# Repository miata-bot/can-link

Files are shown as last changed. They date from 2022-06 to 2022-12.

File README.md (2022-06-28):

# Underglow Sync Device

Very much work in progress software and hardware project built with [Kicad](https://www.kicad.org/) for hardware, and C and [Lua](https://www.lua.org) for software. See [The requirements doc](Requirements.md) for the guts of the project.

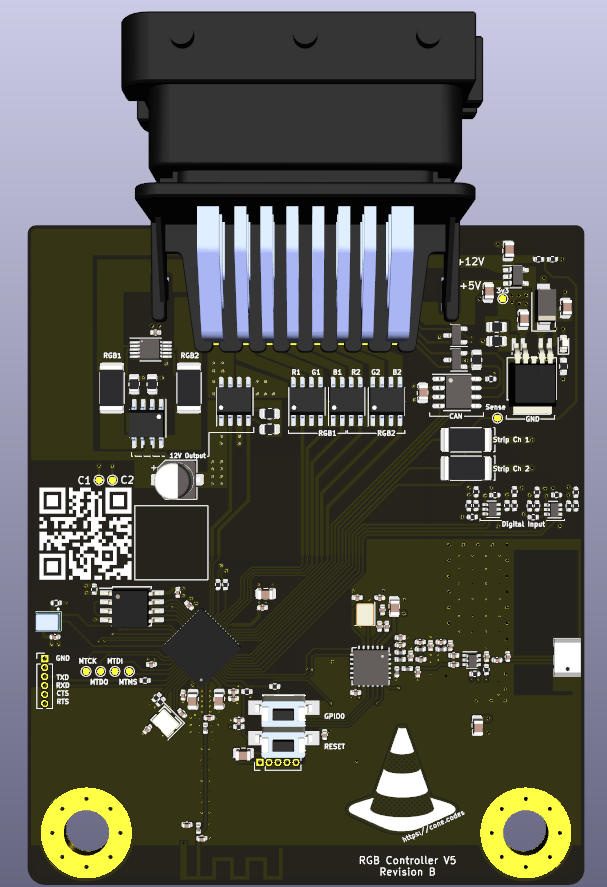
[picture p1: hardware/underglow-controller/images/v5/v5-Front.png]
render


## TLDR

Here's a [Twitter thread](https://twitter.com/pressy4pie/status/1504309482054029315) showing a demo of the ECU integration.
[video link](https://video.twimg.com/ext_tw_video/1504309386151301125/pu/vid/720x1280/zwIcUEVZBSSQAASE.mp4?tag=12).

Here's a [Twitter thread](https://twitter.com/pressy4pie/status/1506779115122139137) showing a demo of the GPS and companion application. [video link](https://video.twimg.com/ext_tw_video/1506778163891740673/pu/vid/720x1630/oxYdaMkSowD5uJmU.mp4?tag=12).

I've written up a few posts on the progress of the project

* [Original hardware design](https://cone.codes/posts/can-link/)
* [Short post on using PWM to drive LEDS](https://cone.codes/posts/nerves-pwm/)
* [Hardware redesign](https://cone.codes/posts/can-link-pt-2/)
* [Hardware reredesign](https://cone.codes/posts/can-link-pt-3/)
* [Hardware rereredesign](https://cone.codes/posts/can-link-pt-4/)
* [Designing a Development test board](https://cone.codes/posts/imx6-devboard/)

## Description

This README acts as a root for all the jillion projects contained within the repo. There is no inherit relationship between any folders. Some are Elixir, some are flutter, etc. One day clean it up. Too much proof of concepting going on right now.

| Folder Name | Description | Language | License |
| ---| --- | --- | --- |
| [hardware](hardware/README.md) | Main hardware designs. Contains schematics, layouts, boms, manufacturing gerbers etc. | KiCad | Creative Commons |
| [firmware](firmware/README.md) | Main Firmware projects. | C++ | MIT |

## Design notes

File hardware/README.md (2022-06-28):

# Hardware Design

Here you'll find the hub for all the sub projects and KiCAD libraries.

| Folder | Description |
| ---| --- |
| [`underglow-controller`](/hardware/underglow-controller/README.md) | RGB controller board |
| - | - |
| [`library`](/hardware/library/README.md) | Library of KiCAD Parts |

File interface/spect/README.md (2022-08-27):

# Software Developer Documentation

These documents are intended for
software developers of potential contributors to
the project's firmware.

## Getting started

First follow the [The getting started guide](Getting-Started.md).
This will take you thru setting up a dev environment to
flash and debug firmware.

## Build Firmware

```bash
cd project_root/firmware/spect
idf.py build
```

## Flash Firmware

1) hold the download button
2) power the device on

```bash
cd project_root/firmware/spect
idf.py flash
```

## Monitor Firmware

```bash
cd project_root/firmware/spect
idf.py monitor
```

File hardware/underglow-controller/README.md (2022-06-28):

# RGB Controller

Device designed to control RGB LEDs and syncronize across multiple nodes
via packet radio.

pcb-front

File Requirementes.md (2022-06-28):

# UNDERGLOW / RGB SYNC PROJECT

I want to make a device that can syncronize underglow
or other RGB lights between two or more cars. Below is a high-level list of all the things I want out of the project.

0) This is not a for profit product, I'm building this for fun.
1) The device should have a CAN interface for aftermarket ECUs and OBD2 capable cars. This notably leaves out interfacing older pre-obd2 cars right now. See [Non CAN enabled applications](#non-can-enabled-systems) for justification and workarounds. See [ECU Support](#ecu-support) for a list of planned support.
2) The device should be WiFi/Bluetooth capable. See the [Hardware](#hardware) section.
3) Every component should be open source where applicable. See the [Licensing](#license) section.
4) It doesn't need to be the cheapest thing. See the [Pricing](#pricing).
5) The device should work offline. See the [Offline Use](#offline-use).
6) The device should create a mesh network to sync devices together. See [Packet Radio](#packet-radio).

## Non CAN Enabled Applications

I decided early on that I simply do not care about this enough to spend time on it. A potential solution to this is an external hardware one. That is, If one wants to inerface a non CAN enabled system, all they would need to do is design their own interface system, and then put their own CAN layer on top. This turns the issue into a software problem, where the interface may be added as a decoder plugin. See the [Firmware Plugin System](#Firmware-Plugin-System) for more info.

## ECU Support

I've written code to support several ECUs already. Much care was put into the system to define how decoding works. It's not "feature complete" yet, but the scafolding is put in place already for dynamic decoder definition. What this means is that I will add support for a handful of common systems up front as I've already done, but adding new ones should be quite easy.

Here's the current supported platform matrix:

| ECU | Coded? | Tested? | Note  |
| --- | --- | --- | ----- |
| MegaSquirt | no | no | Broadcast protocol with default ID |
| Haltech | no | no | Broadcast protocol |
| Maxx | no | no | Default broadcast protocol, too extensible to test every combo? |
| OBD2 | no | no | Enabled in Linux, need to decode messages somehow |
| Speeduino  | no | no | Very similar to MS proto iirc |

## Hardware

~~I've tried this project a few times in the past, and every single time I wish I just started with Linux. I'm sure it's possible to do in an RTOS or even an Arduino system etc. It's just to hard to reason about a system with so much connectivity for me. This puts a much higher price tag because the components selected for the board are just by nature quite a bit more expensive. See the pricing section.~

Designing around a modern SOC right now is just too hard due to the global chip shortage. Maybe I'll try again in the future. For now, I've redesigned the device to use an ESP32-S3 as the "main" chip. ~~and a secondary RP Pico as a coprocessor to do the IO heavy stuff. I'm certain there's better solutions to this but it's what I knew I'd be able to complete without learning a ton of new stuff since I'm on a deadline now.~~

## Firmware

1) The ESP-32 firmware should not use Arduino
2) The firmware should allow for custom plugins via a Lua scripting environment

## Packet Radio

Devices use a RF69 Packet radio to syncronize together. My goal is to keep this system as simple as possible. There should be an accompanying document for the implementation, but the gist of it is that there should be single "producer" node on a network, and many consumers. There may be many networks, they should not interfere. This is accomplished easily via the nature of the packet radios not delivering messages that cannot be decrypted. A network id will just be it's encryption key. This means that networks can be created and destroyed dynamically without collision provided a adequite IDing scheme. UUIDs should work for easy serialization and sharing via QR code or similar. Could also use the ATECCA chip's public key.

One potential idea I have with the radio is to create a "remote" that can control a device similar to the chinese kits. This is of course another piece of hardware that needs to be designed.

## Configuration Interface

There are three ways to configure the device. I plan on shipping a "default" configuration that should just work without any extra setup steps.

The device has a USB mass storage interface that allows storing arbitrary files. I want the main functionality to be implemented in "plugins" (see that section) that can be loaded at runtime. I will ship a default set of plugins to do the some common stuff.

The device has a USB serial port. This means it can be interfaced using existing tools. The first one that comes to mind is Tuner Studio. The INI file could even be stored on the mass storage interface.

The device has a BLE radio. This allows a mobile phone to configure the device via an app.

## Mobile Application

I added BLE onto the device to allow developing a mobile application. I don't really want to make this application myself. I'm hoping this is something I can trick open source passer-bys into building. I've used Flutter to develop a proof of concept application that interfaces the device but it's far from complete. If you're reading this and are interested, get in touch.

## Offline Use

One of my main goals for this device is to have it working in time for [Miatas at the Gap](https://www.gapmiatas.com/) at the end of the year. This means it cannot rely on an active internet connection for use. This does not mean that internet cannot be used, that's why i put a WiFi chip on the board. I don't have any firm planned features that require internet right now, but I do have some ideas. This requirement lead me to use a packet radio for syncing systems together in a meshing network. See [Packet Radio](#packet-radio).

## License

The entire project will be open source. Although I don't expect many direct contributions, I still want the ability for others to be involved with the development easily.

Hardware should be Creative Commons. Software will be mostly MIT or Apache 2. I haven't decied which one yet. Probably Apache 2.

## Pricing

I don't really expect this to be a viable product. The final "price" will probably be whatever it costs to make the device. I may do a croudfunded run of the device depending on what the final BOM turns out to cost. Right now my gut tells me each board will cost about $125 to produce. The passive components are pretty cheap, but there's a lot of them. The CPU is really hard to get right now due to the global chip shortage, same with the WiFi module etc. The connectors are also in short supply.

In the end I don't really care about the price of the device as long as I still find it fun to work on. If I get bored, or interest fades on the idea, I make no commitment to continue producing the device etc.

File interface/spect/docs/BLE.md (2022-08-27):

# BLE Characteristics and Services

## Effect Slot

## Slot

## NodeInfo

Service UUID: ``

| characteristic | name | description |
| - | - | - |
| `` | node list | subscribe then write anything to get a list of nodes |

### Node List

when subscribed to this characteristic, the following payload will be
delievered per each node this device knows about:

| 0..11 | 11..15 | 15-31 |
| node id | reserved | network id |

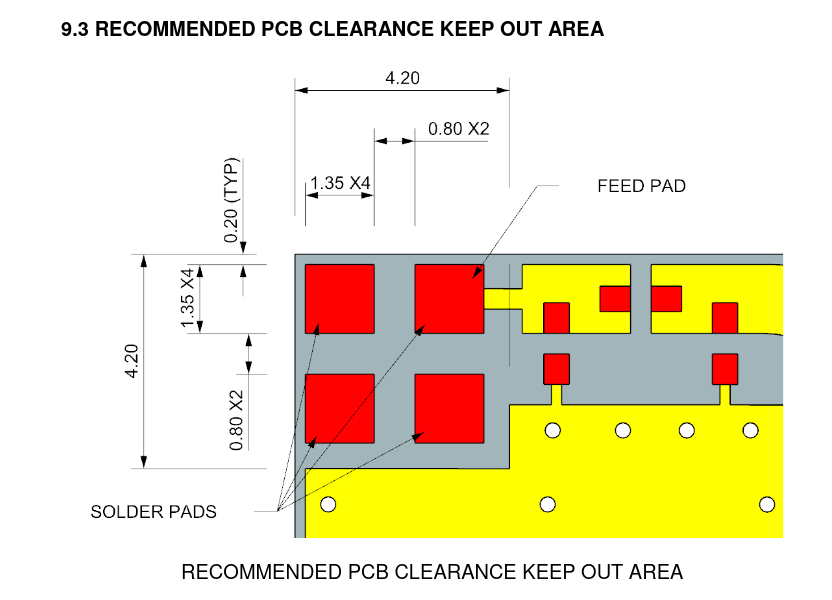
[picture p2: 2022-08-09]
hardware/underglow-controller/images/v5/wifi-antenna-keepout-area.png

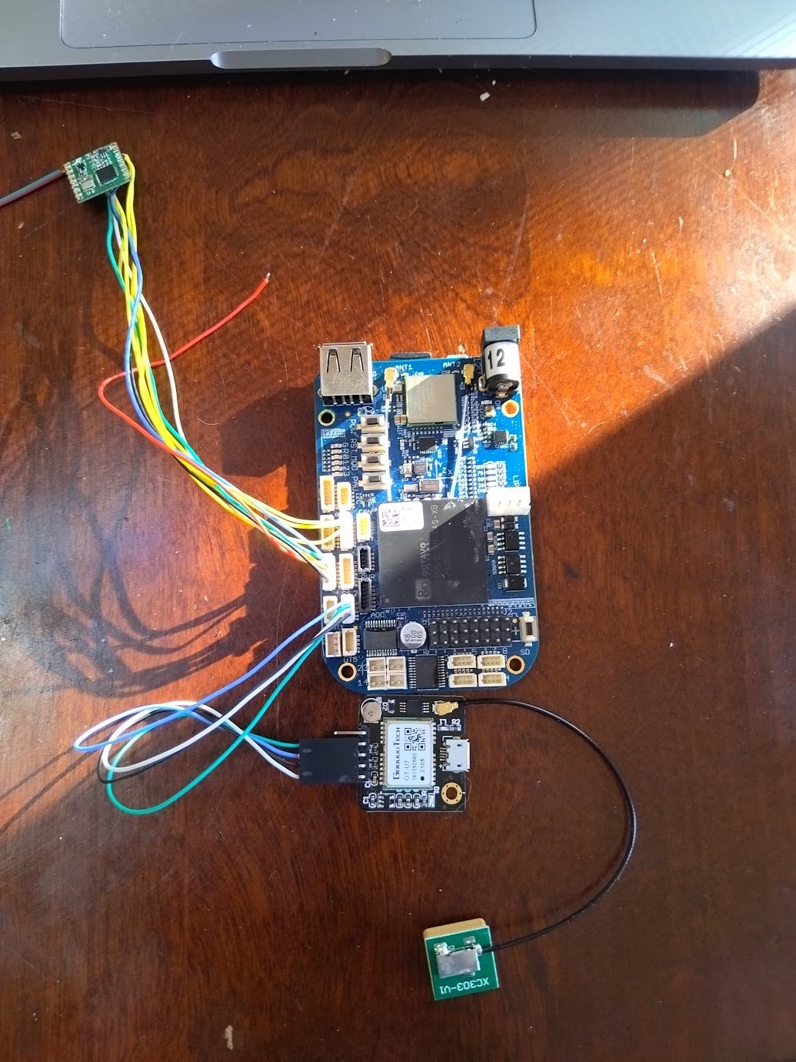
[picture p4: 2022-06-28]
hardware/underglow-controller/images/prototype/beagleblue-prototype.jpg

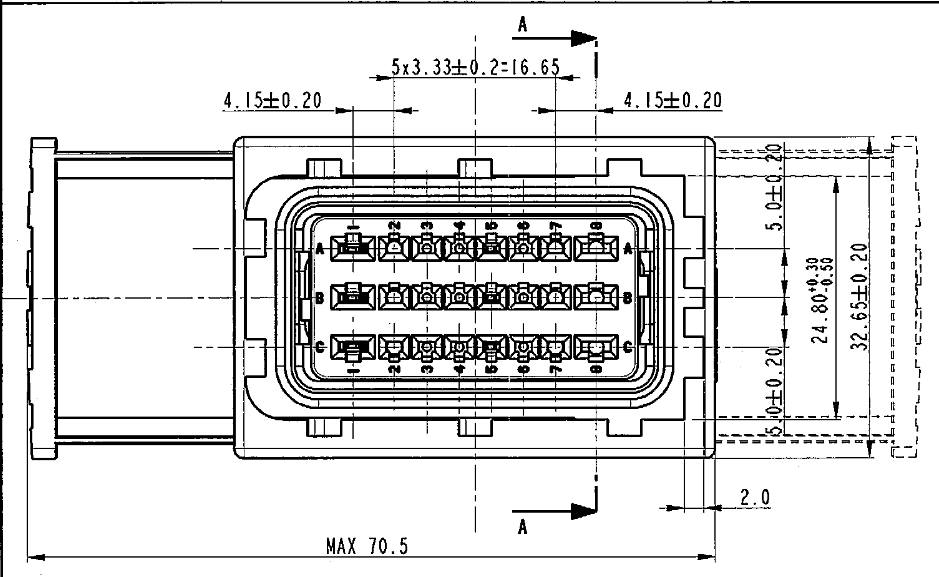
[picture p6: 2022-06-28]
hardware/underglow-controller/images/wiring/Connector-Pinout.png

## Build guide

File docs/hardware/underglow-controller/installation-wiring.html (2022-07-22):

# installation-wiring

## Diagram

## Bill of Materials

Id | Description | Qty | Unit | Designators
1 | Cable, 2 wires | 0 | m | W5
2 | Cable, 3 wires | 0 | m | W6
3 | Cable, 4 wires | 0 | m | Strip1_W1, Strip2_W1, W1, W2
4 | Connector | 2 | | F1, F2
5 | Connector, BK | 3
6 | Connector, Bosch_Style, socket, 5 pins | 1 | | X6
7 | Connector, Delphi_Sicma_24, female, 24 pins | 1 | | X1
8 | Connector, JST SM, female, 4 pins | 12 | | Strip1_X1, Strip1_X2, Strip1_X4, Strip1_X5, Strip1_X7, Strip1_X8, Strip2_X1, Strip2_X2, Strip2_X4, Strip2_X5, Strip2_X7, Strip2_X8
9 | Connector, male, 4 pins | 2 | | X4, X5
10 | Connector, strip, 4 pins | 6 | | Strip1_X3, Strip1_X6, Strip1_X9, Strip2_X3, Strip2_X6, Strip2_X9

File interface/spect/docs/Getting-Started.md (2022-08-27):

# Settingup a development environment

This should be done on Linux. if you're not using Linux,
get rekt i guess.

* clone this repo: `git clone git@github.com:miata-bot/can-link.git`
* clone submodules:  `git submodule --init --recursive`
* install [esp idf](https://docs.espressif.com/projects/esp-idf/en/v4.4.2/esp32s3/get-started/index.html)
* apply patches to sqlite3: `cd firmware/spect/components/esp-idf-sqlite3 && git patch am ../*.patch`
* install [asdf](https://asdf-vm.com/)
* install erlang and elixir: `cd interface/spect && asdf install`
* fetch dependencies: `cd interface/spect && mix deps.get`
* run migrations: `cd interface/spect && mix ecto.migrate`
* build firmware: `cd firmware/spect && idf.py build`

If and only of these stepes succeed should you procede.
Return to the [README](README.md)

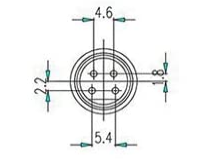
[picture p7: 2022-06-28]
hardware/underglow-controller/images/wiring/RGB-Female.png

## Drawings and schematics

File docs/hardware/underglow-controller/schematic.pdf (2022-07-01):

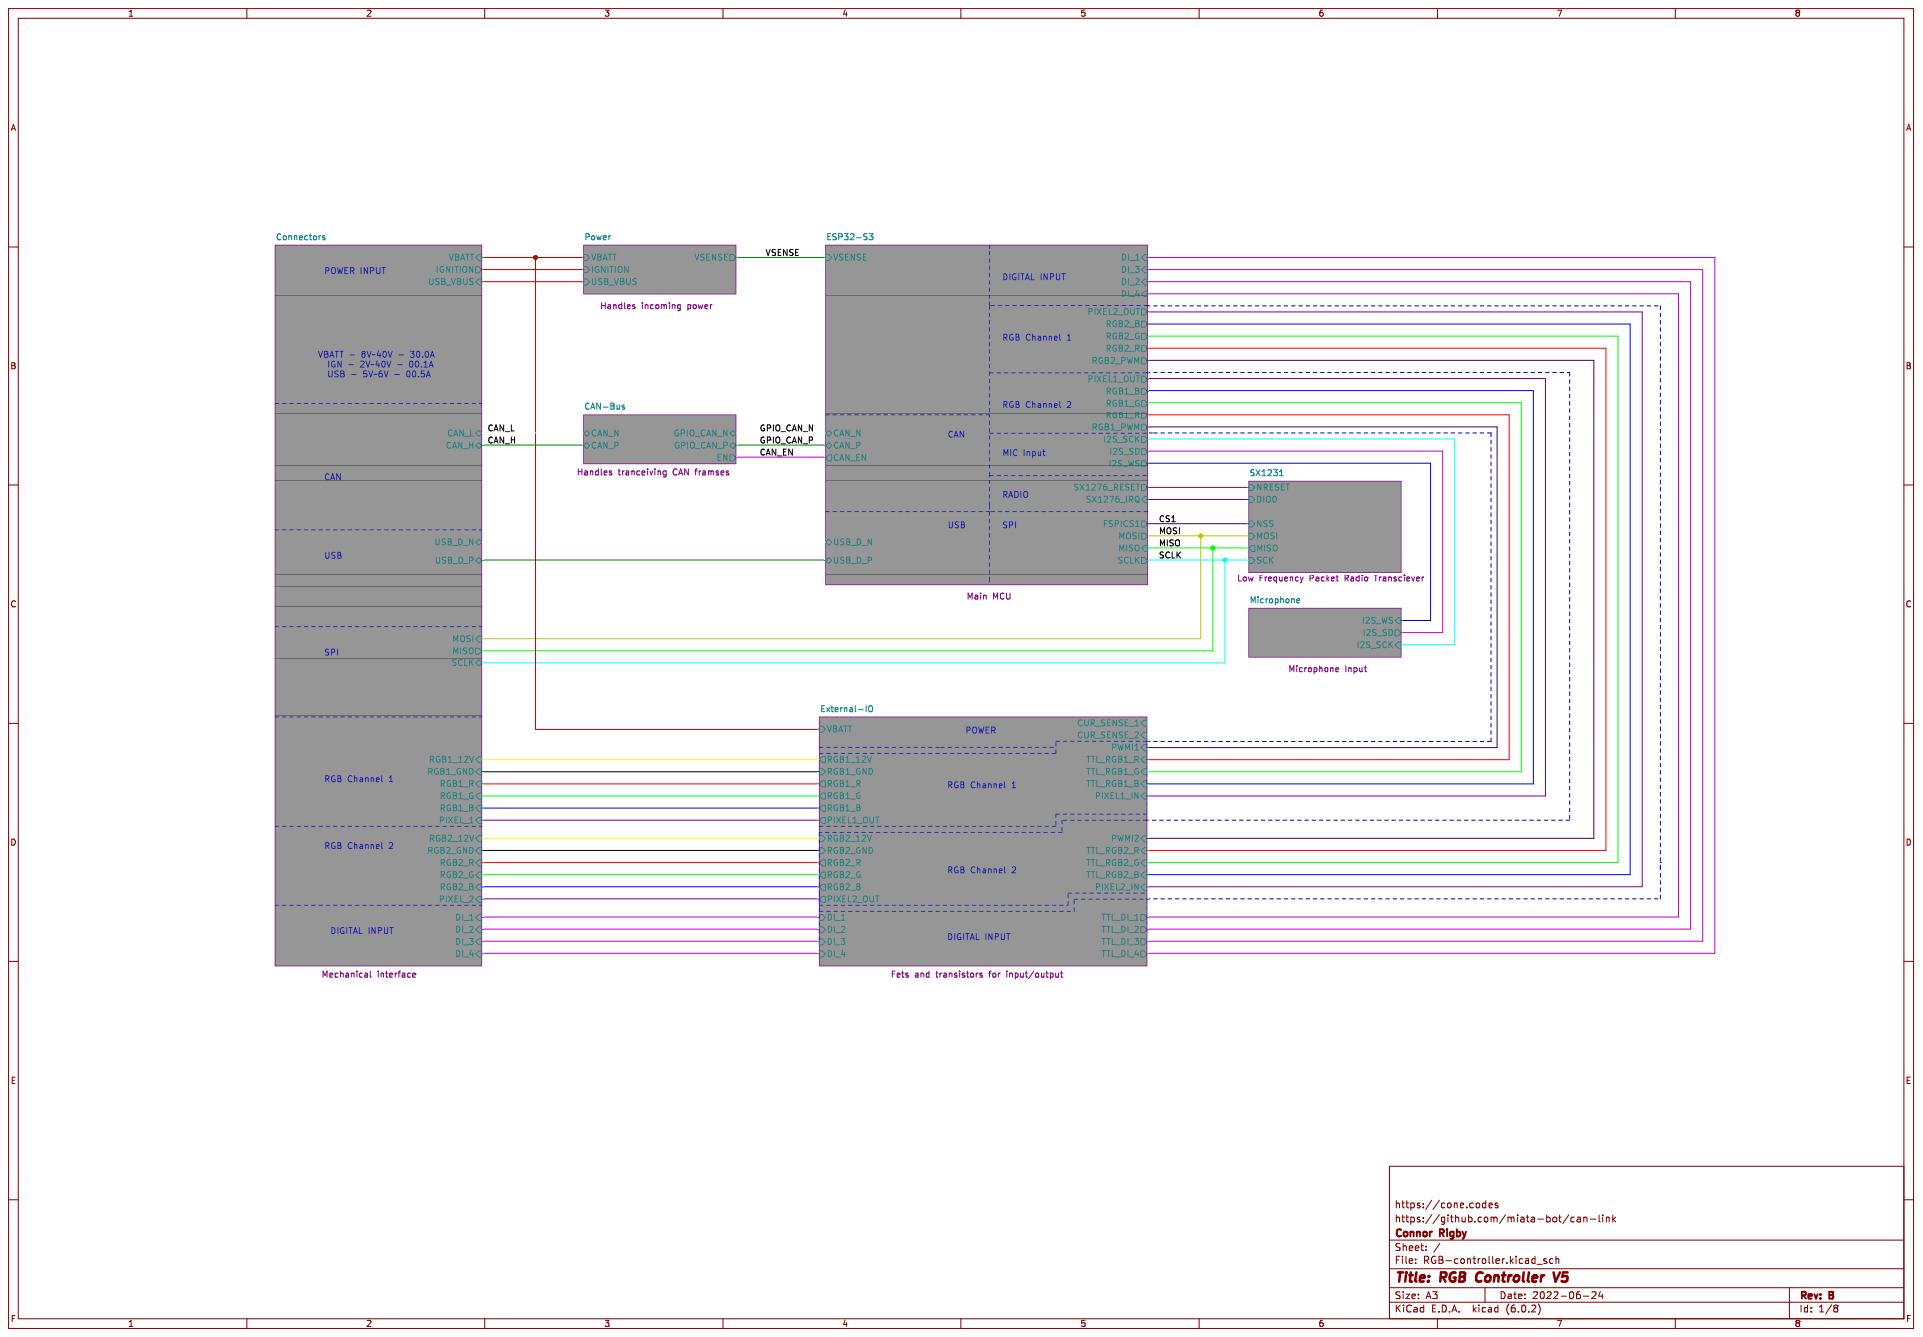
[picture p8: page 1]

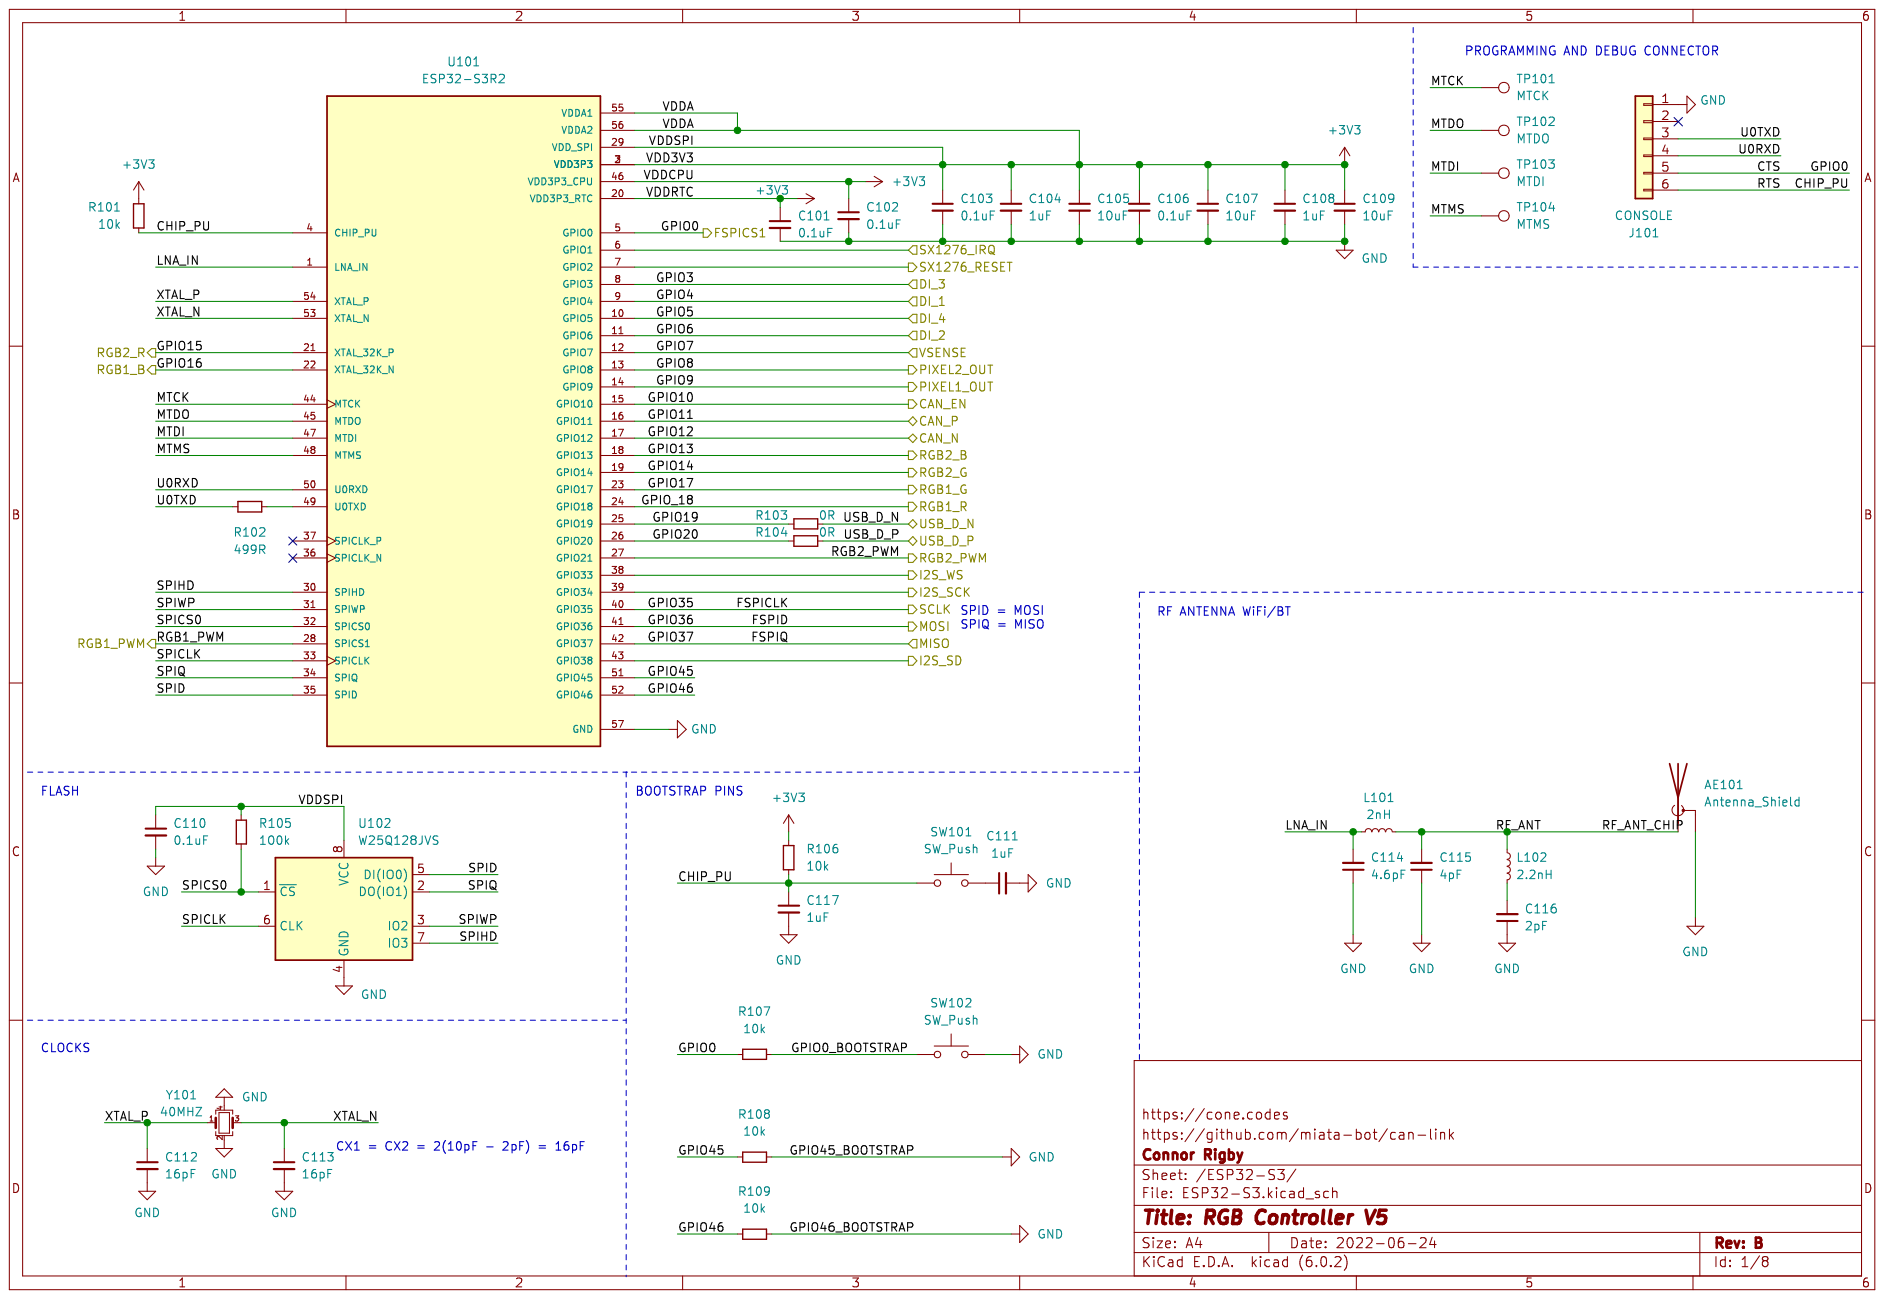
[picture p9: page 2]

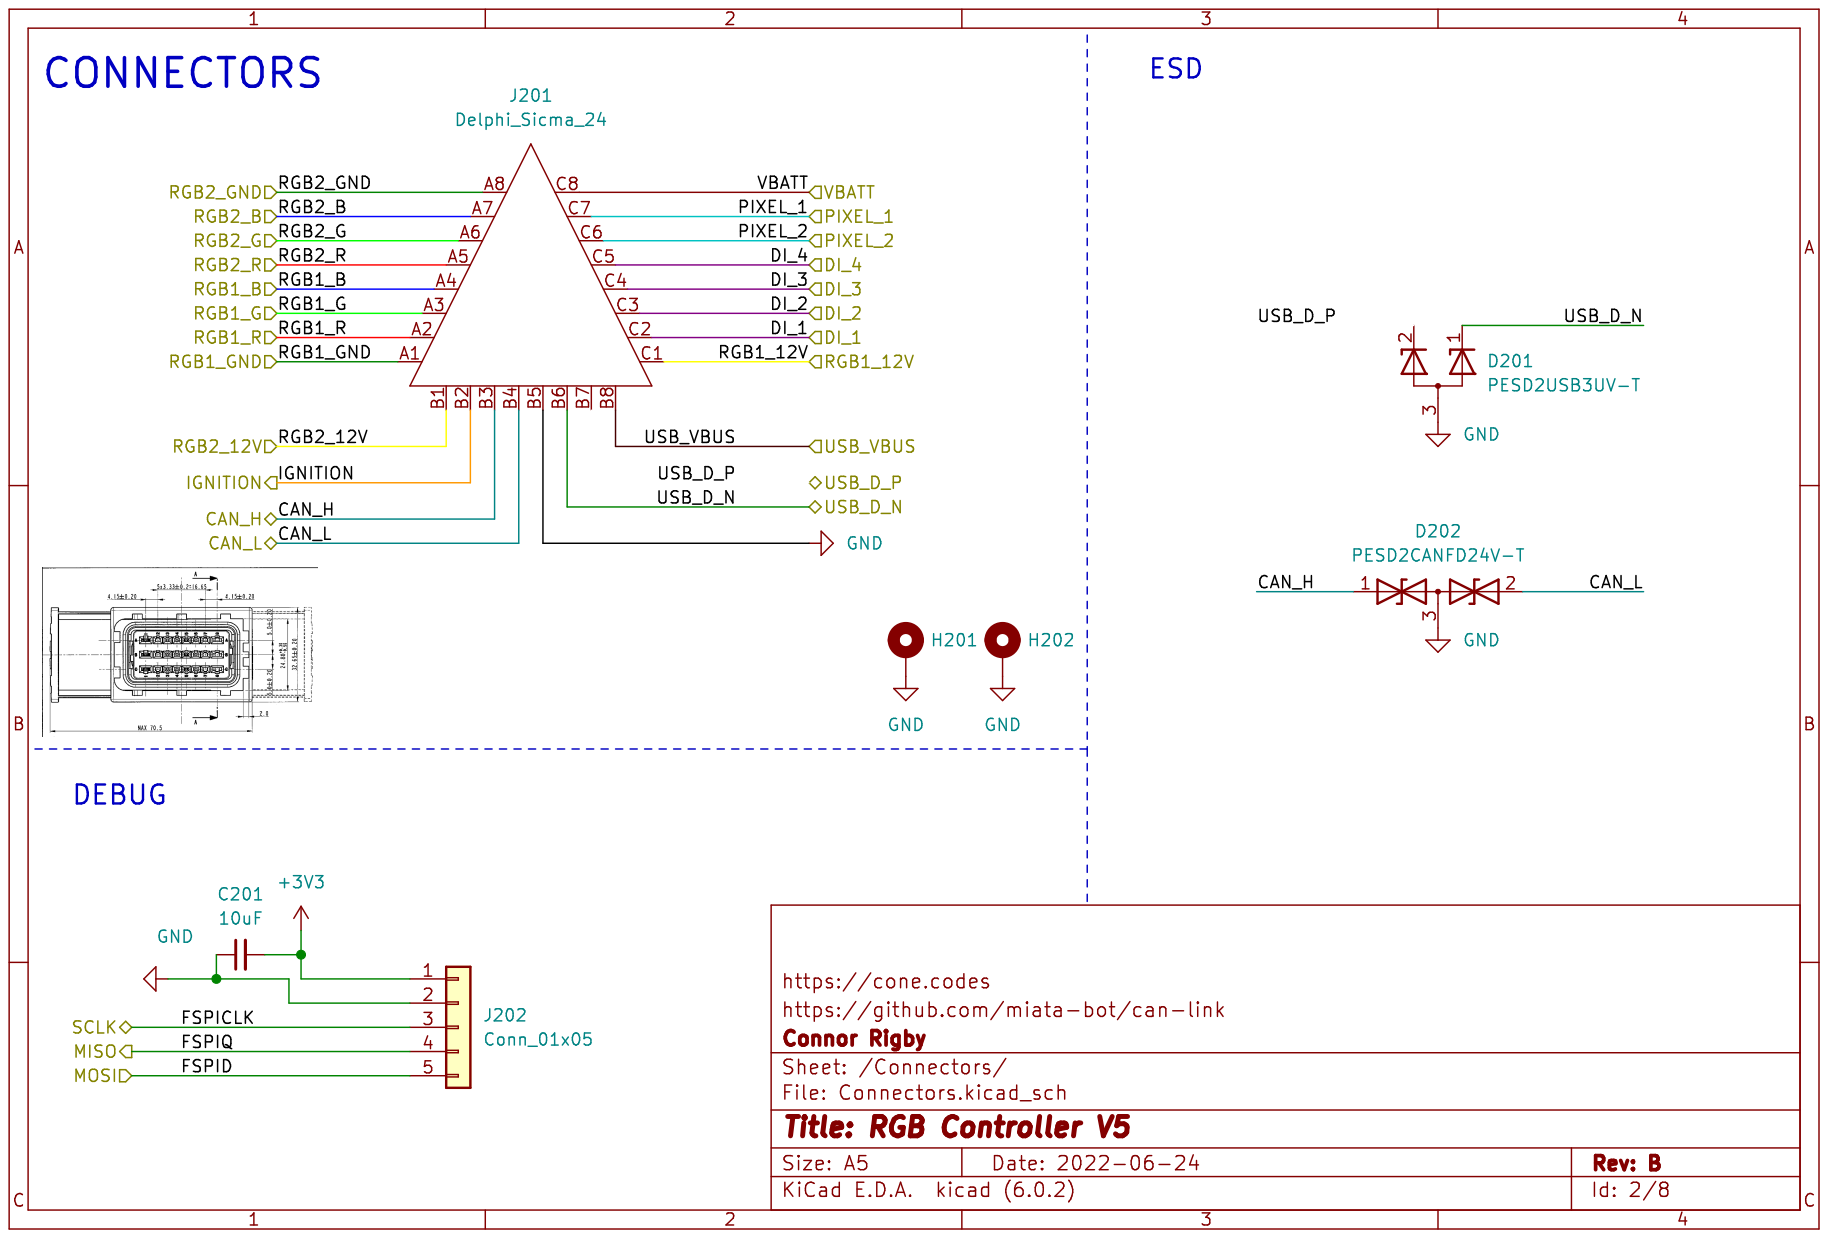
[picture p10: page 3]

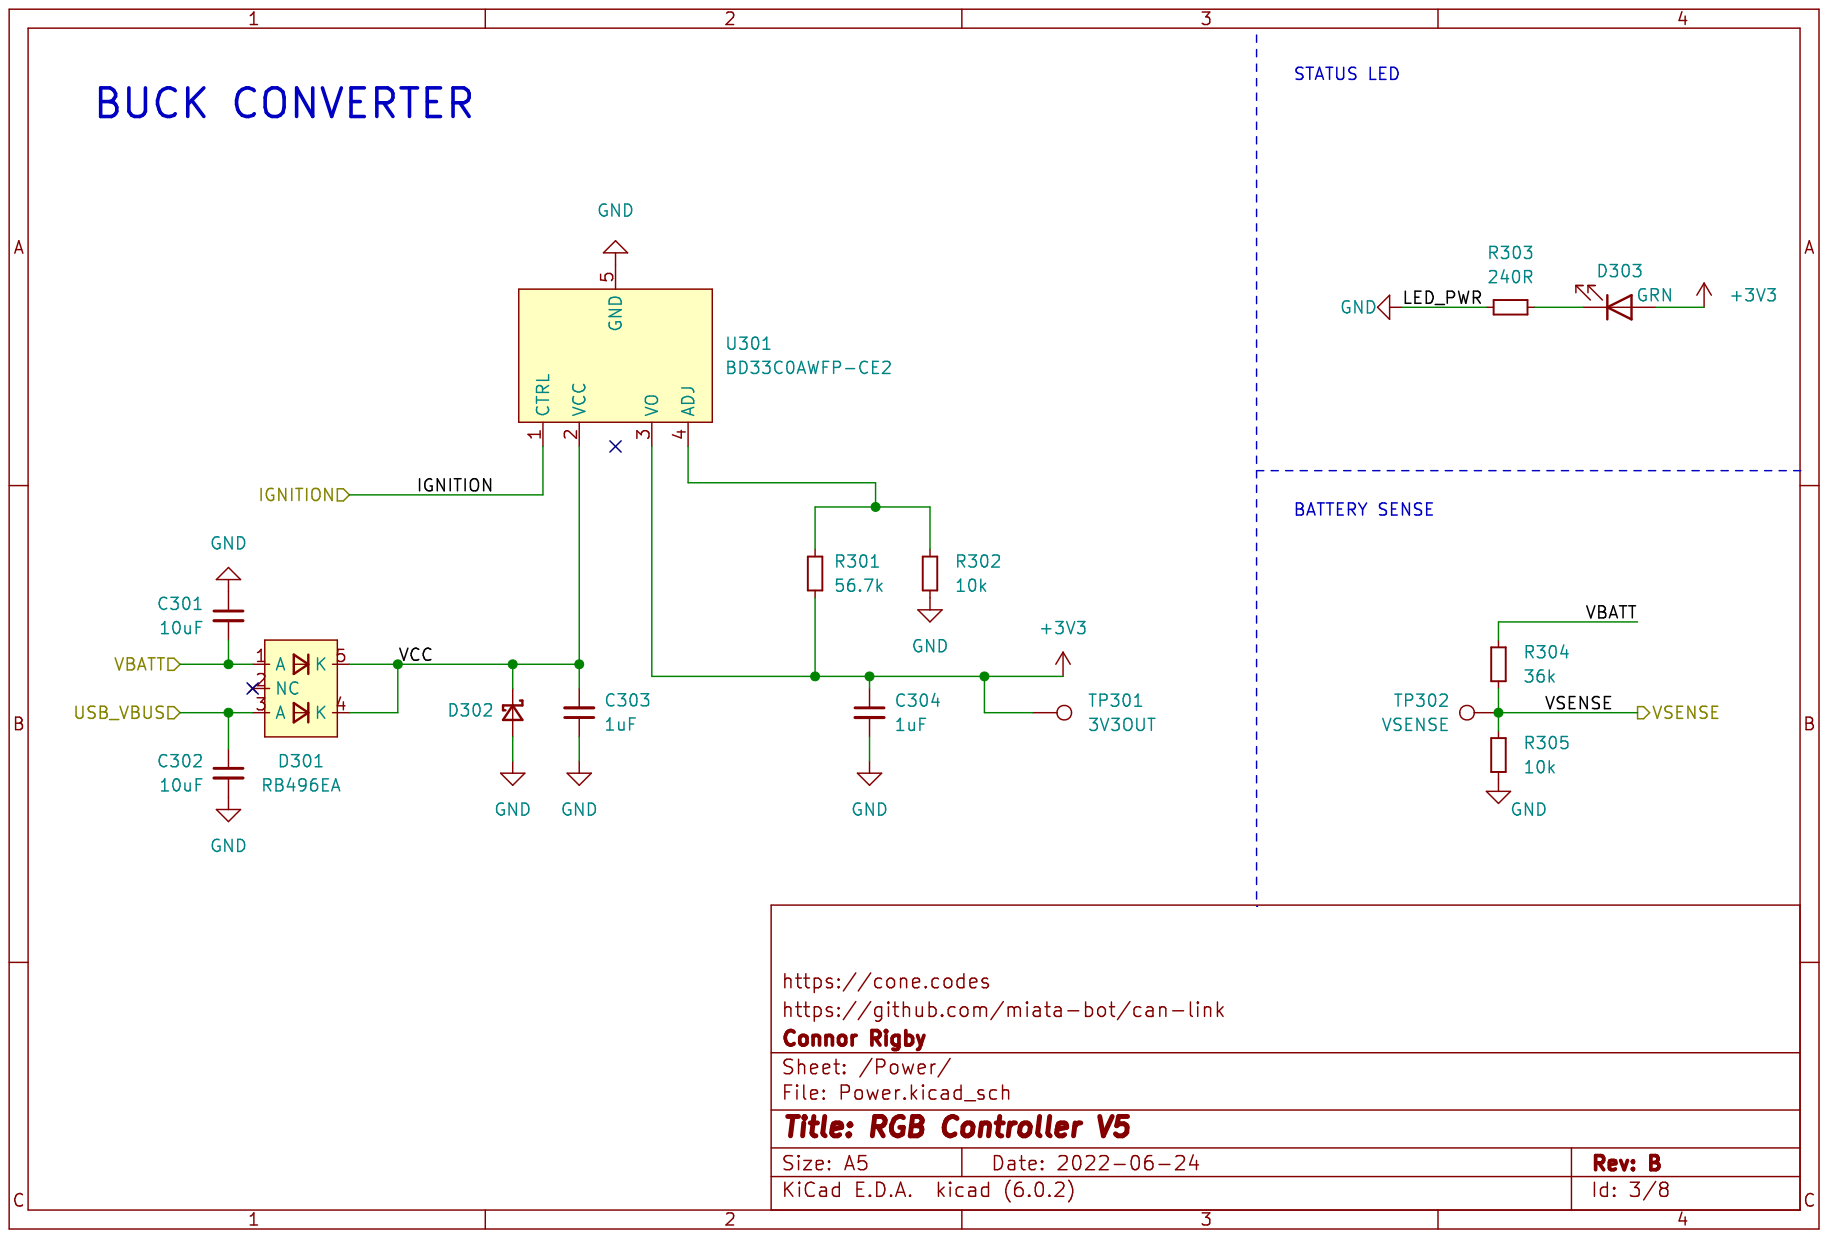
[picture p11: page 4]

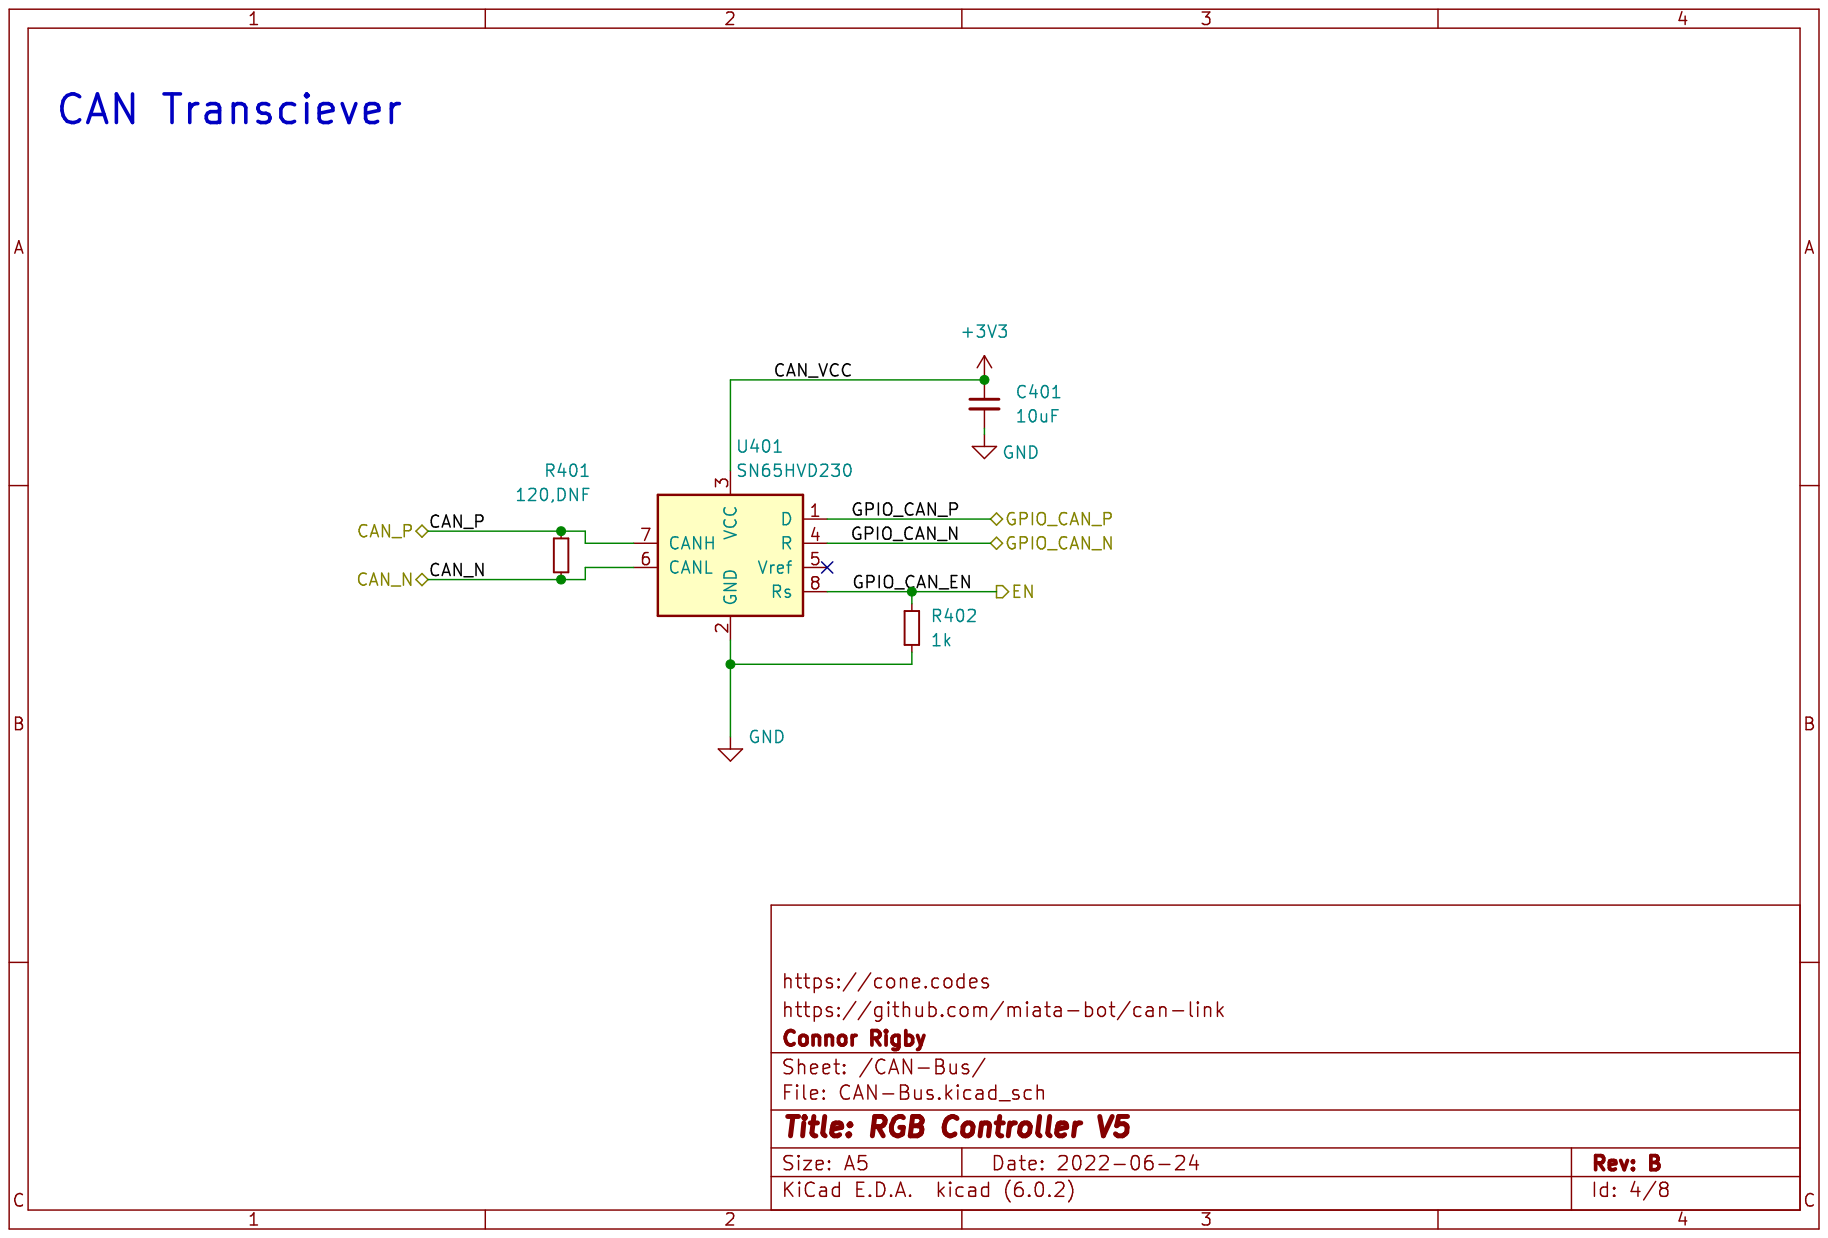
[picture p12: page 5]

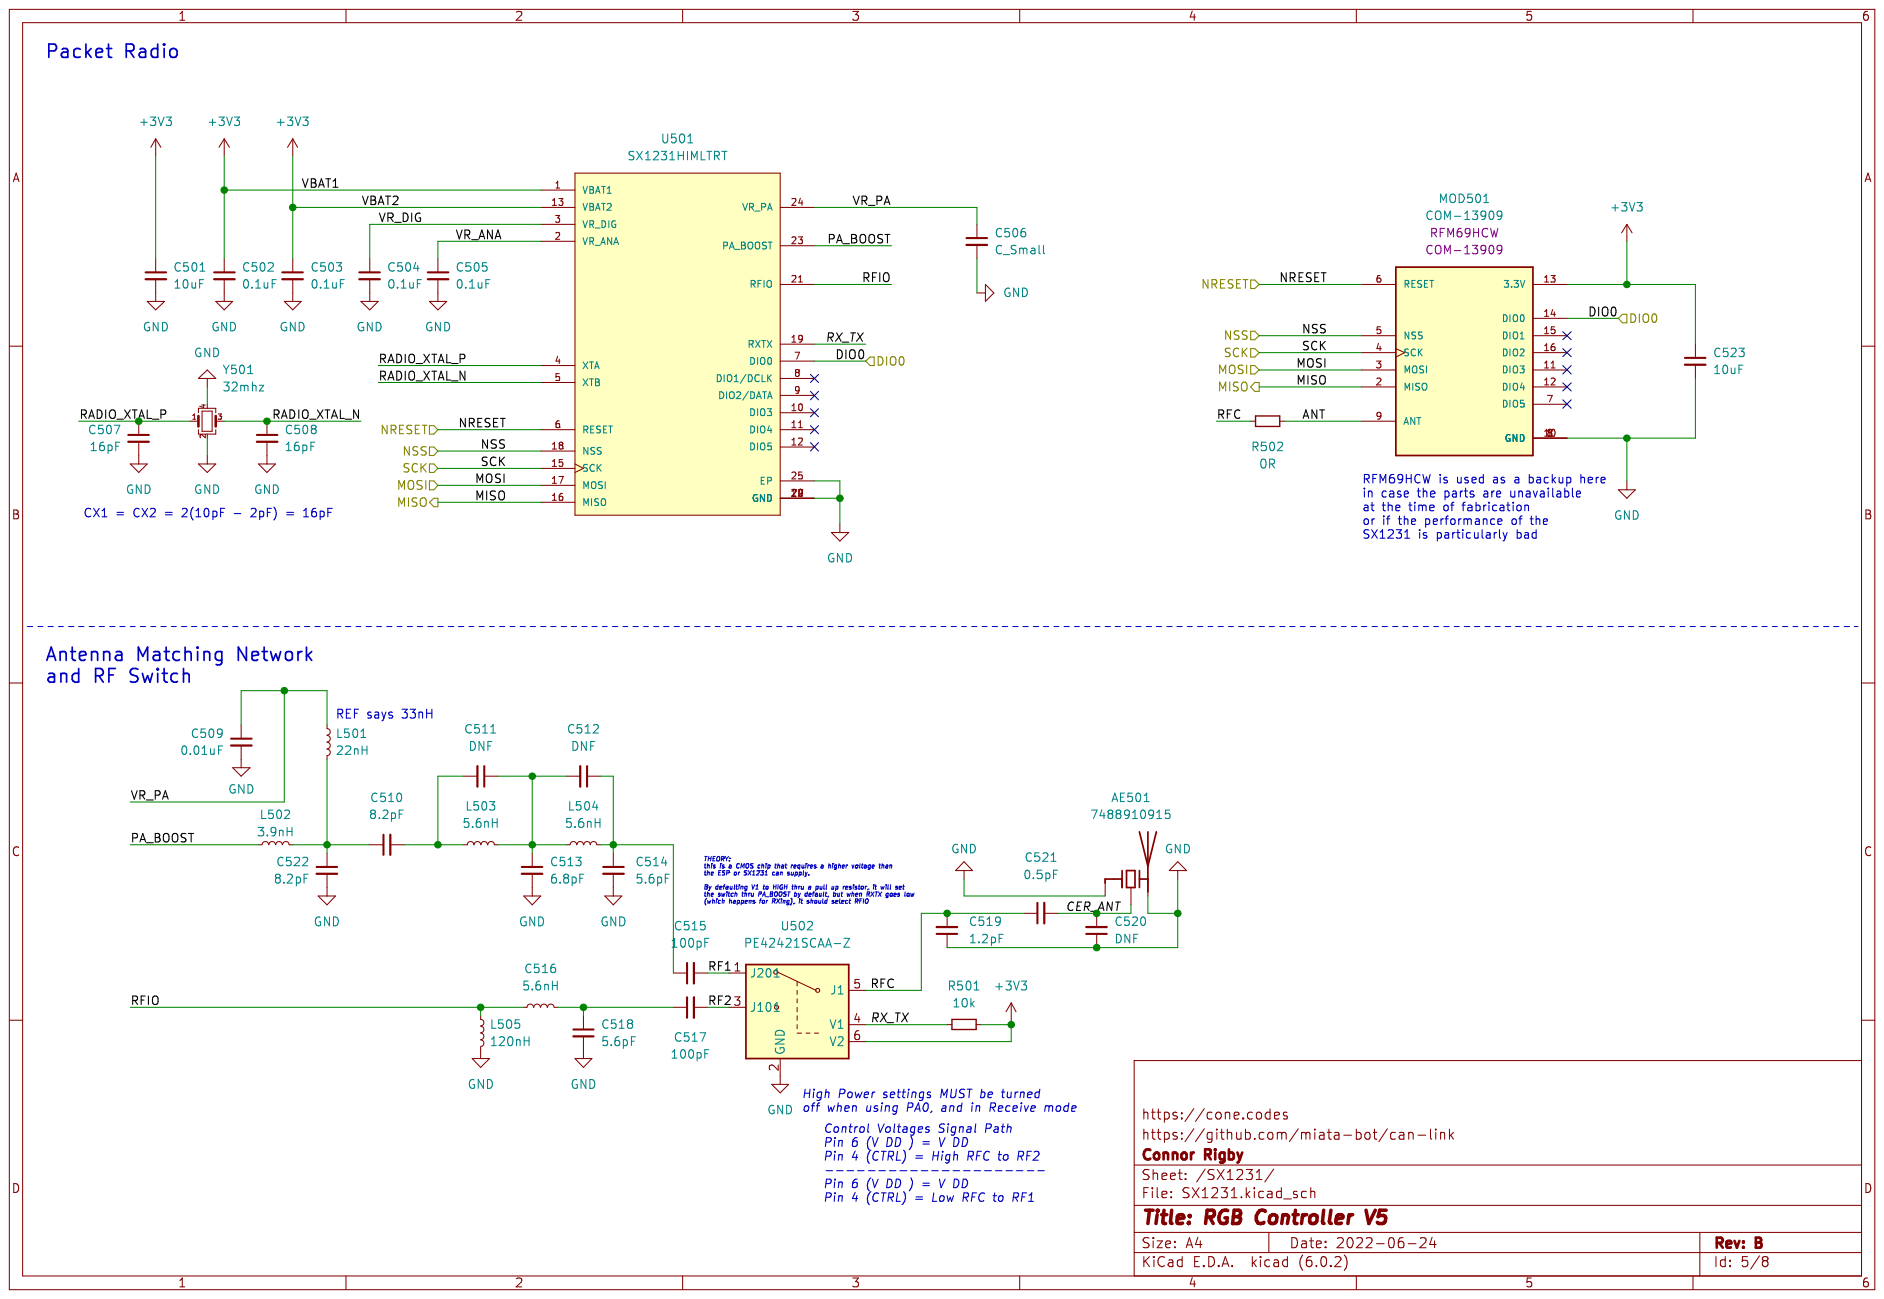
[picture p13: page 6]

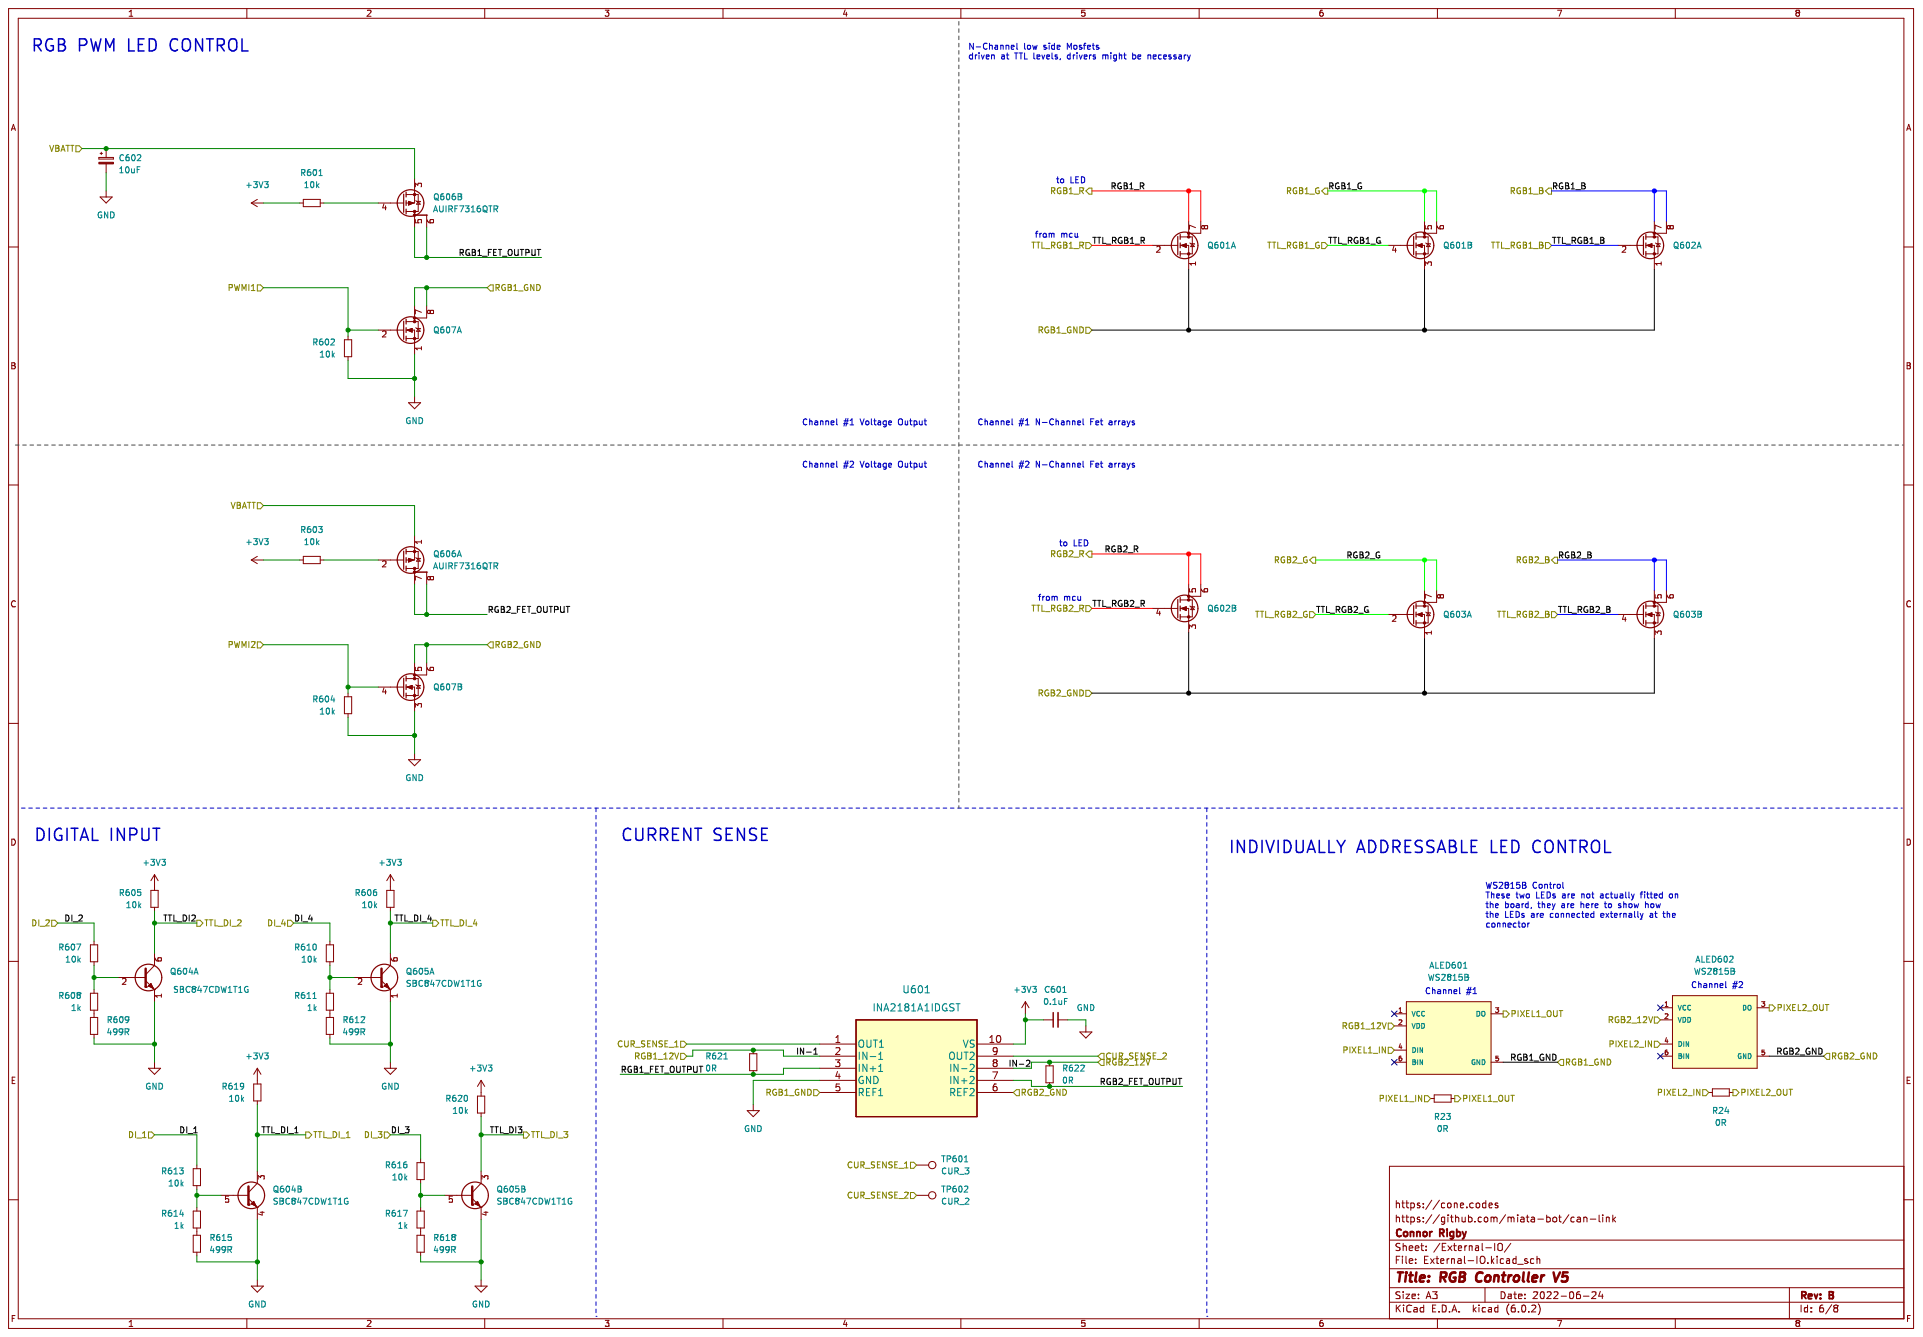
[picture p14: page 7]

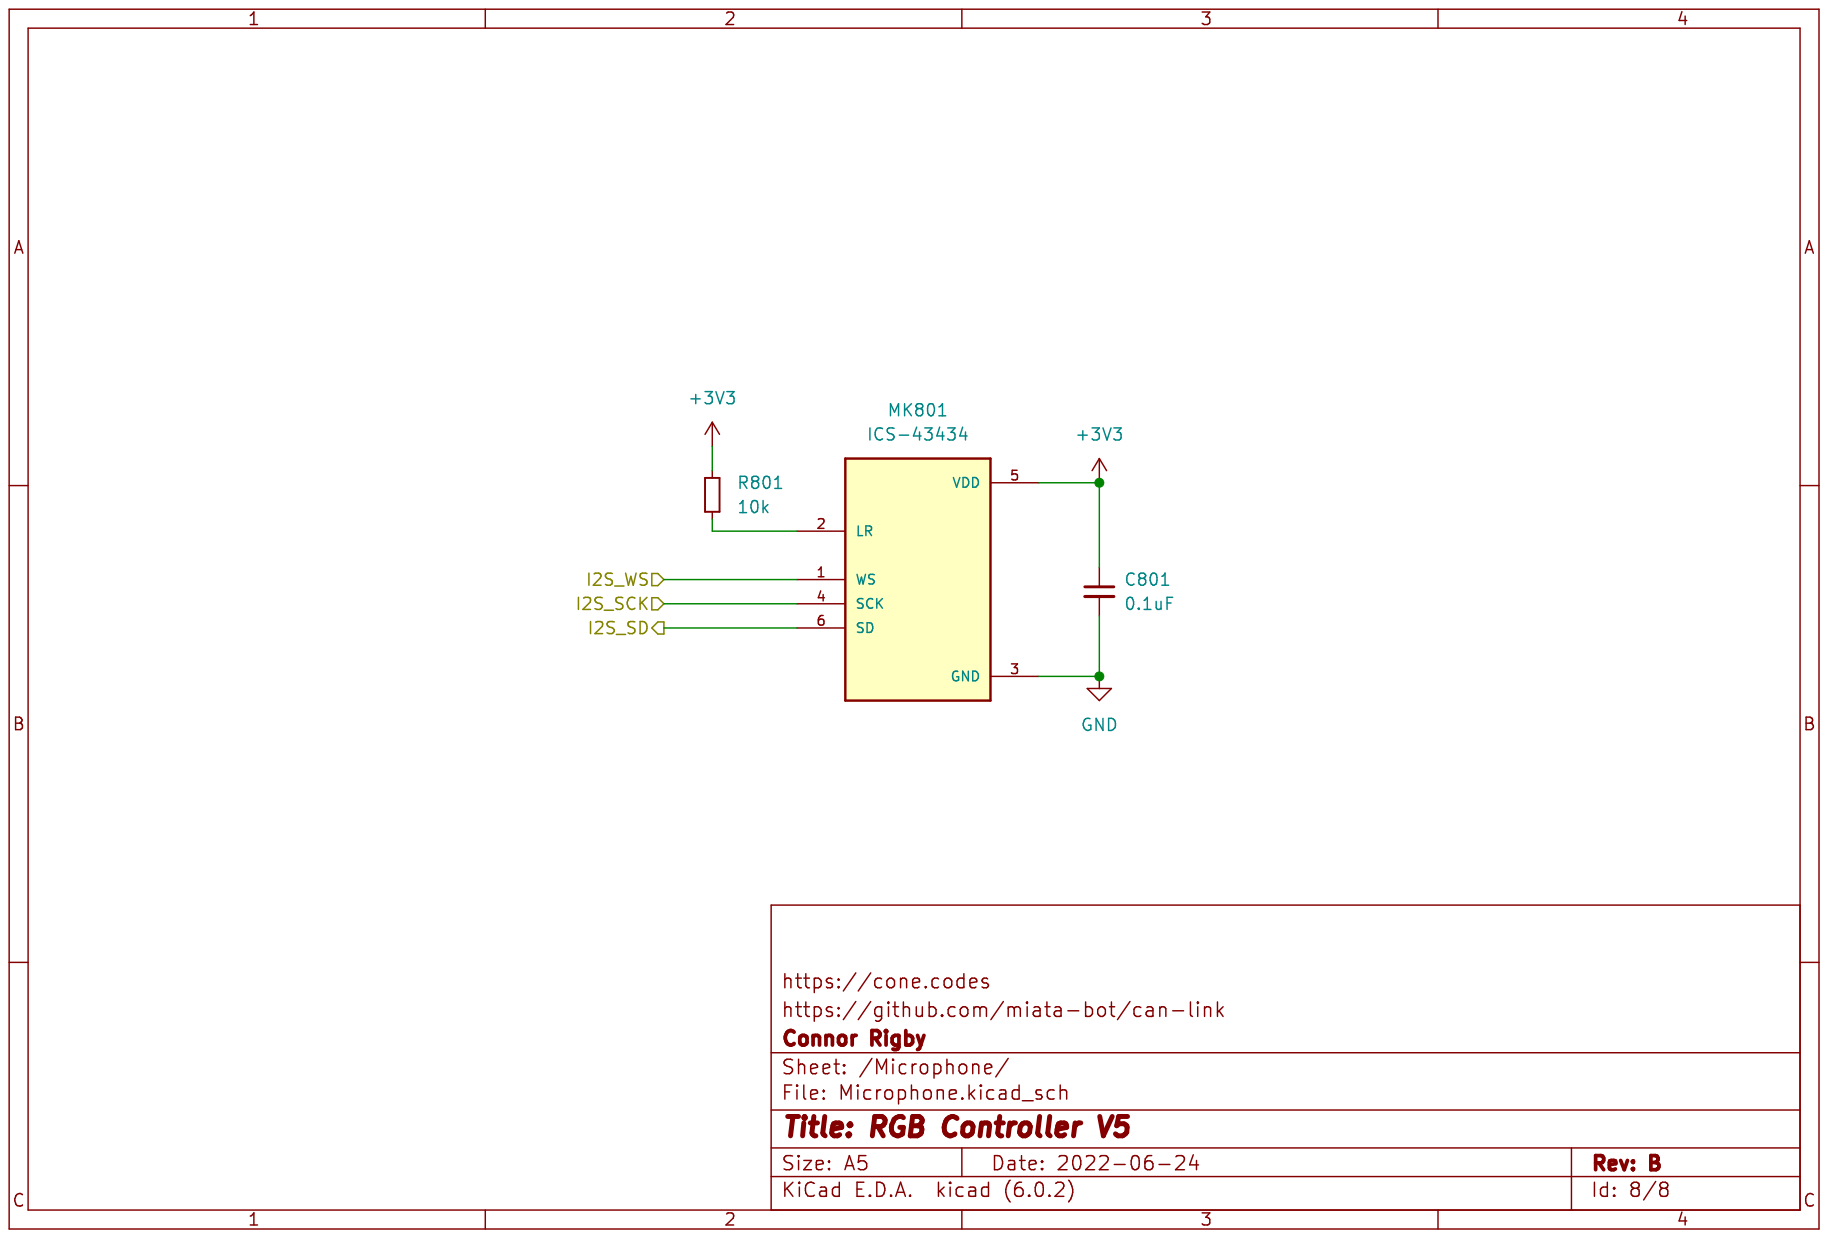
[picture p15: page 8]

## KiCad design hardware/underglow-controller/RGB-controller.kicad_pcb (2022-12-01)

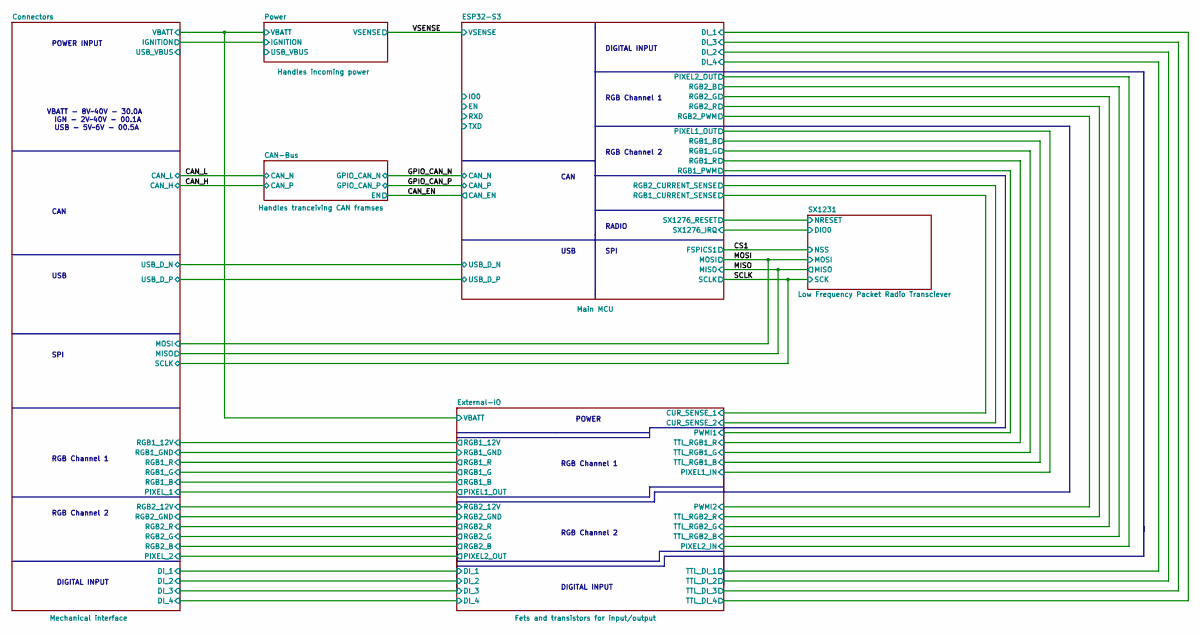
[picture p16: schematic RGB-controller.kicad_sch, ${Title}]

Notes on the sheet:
CAN
RGB Channel 2
USB
RGB Channel 1
SPI
DIGITAL INPUT
POWER INPUT
VBATT - 8V~40V - 30.0A IGN - 2V~40V - 00.1A USB - 5V~6V - 00.5A
POWER
RADIO

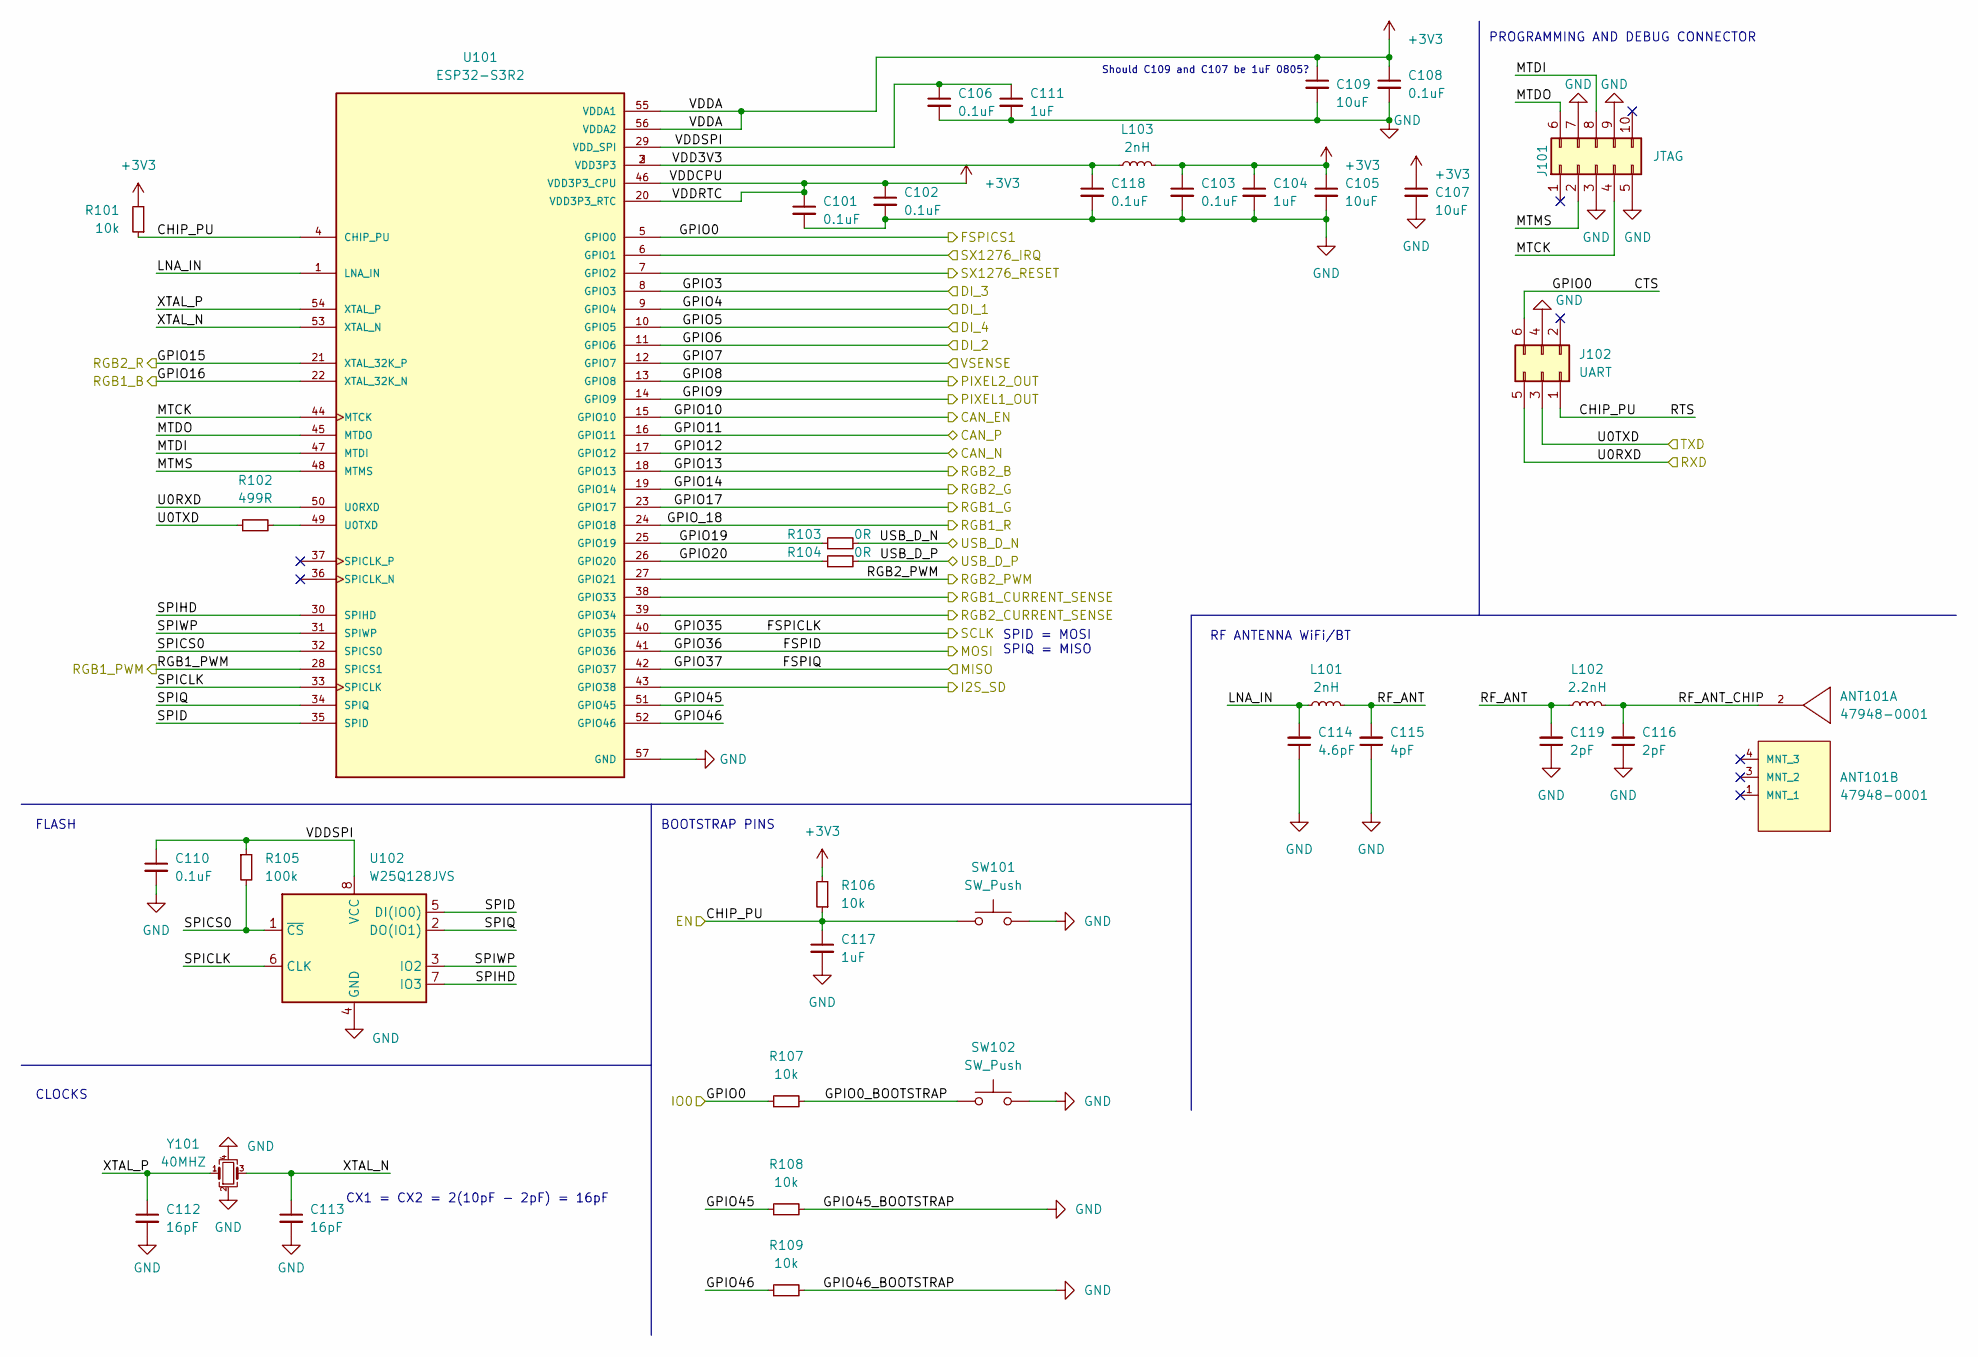
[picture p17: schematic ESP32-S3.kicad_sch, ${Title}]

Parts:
ANT101: 47948-0001; Molex-47948-0001-0-0-0; Digikey WM4893CT-ND
C101, C102, C103, C106, C108, C110, C118: 0.1uF; C_0402_1005Metric; Digikey CGA2B1X7R1C104M050BC
C104, C111, C117: 1uF; C_0402_1005Metric; Digikey CGA2B1X7T0G105M050BC
C105, C107, C109: 10uF; C_0805_2012Metric; Digikey GRT21BC81A106KE01L
C112, C113: 16pF; C_0402_1005Metric; Digikey GCM1555C1H160JA16D
C114: 4.6pF; C_0402_1005Metric; Digikey CBR04C469B5GAC
C115: 4pF; C_0402_1005Metric; Digikey UMK105UJ040CV-F
C116, C119: 2pF; C_0402_1005Metric; Digikey UMK105CK020CVHF
J101: JTAG; Tag-Connect_TC2050-IDC-FP_2x05_P1.27mm_Vertical; Digikey TC2050-IDC
J102: UART; Tag-Connect_TC2030-IDC-FP_2x03_P1.27mm_Vertical; Digikey TC2030-IDC
L101, L103: 2nH; L_0402_1005Metric; Digikey LQG15HN2N0C02D
L102: 2.2nH; L_0402_1005Metric; Digikey L-07C2N2SV6T
R101, R106, R107, R108, R109: 10k; R_0402_1005Metric; Digikey RMCF0402JT10K0
R102: 499R; R_0402_1005Metric; Digikey RMCF0402FT499R
R103, R104: 0R; R_0402_1005Metric; Digikey RC0402JR-070RP
R105: 100k; R_0402_1005Metric; Digikey RNCF0402DTE100K
SW101, SW102: SW_Push; SW_RS-032G05A3-SMRT; Digikey RS032G05A3SMRT
U101: ESP32-S3R2; QFN-56; Digikey ESP32-S3
U102: W25Q128JVS; SOIC-8W_5.3x5.3mm_P1.27mm; Digikey W25Q128JVS
Y101: 40MHZ; Crystal_SMD_3225-4Pin_3.2x2.5mm; Digikey ECS-400-10-37B2-CKY-TR

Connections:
+3V3: C101.1, C102.1, C103.1, C104.1, C105.1, C107.1, C108.1, C109.1, L103.2, R101.2, R106.2, U101.20 (VDD3P3_RTC), U101.46 (VDD3P3_CPU), U101.55 (VDDA1), U101.56 (VDDA2); also elsewhere on the board
/CAN_EN: U101.15 (GPIO10); also elsewhere on the board
/CS1: J102.6, R107.1, U101.5 (GPIO0); also elsewhere on the board
/ESP32-S3/CHIP_PU: C117.1, J102.1, R101.1, R106.1, SW101.1, U101.4 (CHIP_PU)
/ESP32-S3/GPIO0_BOOTSTRAP: R107.2, SW102.1
/ESP32-S3/GPIO3: U101.8 (GPIO3); also elsewhere on the board
/ESP32-S3/GPIO4: U101.9 (GPIO4); also elsewhere on the board
/ESP32-S3/GPIO5: U101.10 (GPIO5); also elsewhere on the board
/ESP32-S3/GPIO6: U101.11 (GPIO6); also elsewhere on the board
/ESP32-S3/GPIO8: U101.13 (GPIO8); also elsewhere on the board
/ESP32-S3/GPIO9: U101.14 (GPIO9); also elsewhere on the board
/ESP32-S3/GPIO13: U101.18 (GPIO13); also elsewhere on the board
/ESP32-S3/GPIO14: U101.19 (GPIO14); also elsewhere on the board
/ESP32-S3/GPIO15: U101.21 (XTAL_32K_P); also elsewhere on the board
/ESP32-S3/GPIO16: U101.22 (XTAL_32K_N); also elsewhere on the board
/ESP32-S3/GPIO17: U101.23 (GPIO17); also elsewhere on the board
/ESP32-S3/GPIO19: R103.1, U101.25 (GPIO19)
/ESP32-S3/GPIO20: R104.1, U101.26 (GPIO20)
/ESP32-S3/GPIO45: R108.1, U101.51 (GPIO45)
/ESP32-S3/GPIO46: R109.1, U101.52 (GPIO46)
/ESP32-S3/GPIO_18: U101.24 (GPIO18); also elsewhere on the board
/ESP32-S3/I2S_SD: U101.43 (GPIO38)
/ESP32-S3/LNA_IN: C114.2, L101.1, U101.1 (LNA_IN)
/ESP32-S3/MTCK: J101.4, U101.44 (MTCK)
/ESP32-S3/MTDI: J101.8, U101.47 (MTDI)
/ESP32-S3/MTDO: J101.6, U101.45 (MTDO)
/ESP32-S3/MTMS: J101.2, U101.48 (MTMS)
/ESP32-S3/RF_ANT: C115.2, C119.2, L101.2, L102.1
/ESP32-S3/RF_ANT_CHIP: ANT101.2 (FEEDING_PAD), C116.2, L102.2
/ESP32-S3/RGB1_CURRENT_SENSE: U101.38 (GPIO33); also elsewhere on the board
/ESP32-S3/RGB1_PWM: U101.28 (SPICS1); also elsewhere on the board
/ESP32-S3/RGB2_CURRENT_SENSE: U101.39 (GPIO34); also elsewhere on the board
/ESP32-S3/RGB2_PWM: U101.27 (GPIO21); also elsewhere on the board
/ESP32-S3/SPICLK: U101.33 (SPICLK), U102.6 (CLK)
/ESP32-S3/SPICS0: R105.2, U101.32 (SPICS0), U102.1 (~CS)
/ESP32-S3/SPID: U101.35 (SPID), U102.5 (DI(IO0))
/ESP32-S3/SPIHD: U101.30 (SPIHD), U102.7 (IO3)
/ESP32-S3/SPIQ: U101.34 (SPIQ), U102.2 (DO(IO1))
/ESP32-S3/SPIWP: U101.31 (SPIWP), U102.3 (IO2)
/ESP32-S3/U0RXD: J102.5, U101.50 (U0RXD)
/ESP32-S3/U0TXD: J102.3, R102.1
/ESP32-S3/USB_D_N: R103.2
/ESP32-S3/USB_D_P: R104.2
/ESP32-S3/VDD3V3: C118.1, L103.1, U101.2 (VDD3P3), U101.3 (VDD3P3)
/ESP32-S3/VDDSPI: C106.1, C110.1, C111.1, R105.1, U101.29 (VDD_SPI), U102.8 (VCC)
/ESP32-S3/XTAL_N: C113.1, U101.53 (XTAL_N), Y101.3
/ESP32-S3/XTAL_P: C112.1, U101.54 (XTAL_P), Y101.1
/GPIO_CAN_N: U101.17 (GPIO12); also elsewhere on the board
/GPIO_CAN_P: U101.16 (GPIO11); also elsewhere on the board
/MISO: U101.42 (GPIO37); also elsewhere on the board
/MOSI: U101.41 (GPIO36); also elsewhere on the board
/SCLK: U101.40 (GPIO35); also elsewhere on the board
/SX1231/DIO0: U101.6 (GPIO1); also elsewhere on the board
/SX1231/NRESET: U101.7 (GPIO2); also elsewhere on the board
/VSENSE: U101.12 (GPIO7); also elsewhere on the board
GND: C101.2, C102.2, C103.2, C104.2, C105.2, C106.2, C107.2, C108.2, C109.2, C110.2, C111.2, C112.2, C113.2, C114.1, C115.1, C116.1, C117.2, C118.2, C119.1, J101.3, J101.5, J101.7, J101.9, J102.4, R108.2, R109.2, SW101.2, SW102.2, U101.57 (GND), U102.4 (GND), Y101.2, Y101.4; also elsewhere on the board
unnamed: R102.2, U101.49 (U0TXD)

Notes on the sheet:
CX1 = CX2 = 2(10pF - 2pF) = 16pF
SPID = MOSI SPIQ = MISO
BOOTSTRAP PINS
FLASH
CLOCKS
PROGRAMMING AND DEBUG CONNECTOR
RF ANTENNA WiFi/BT
Should C109 and C107 be 1uF 0805?

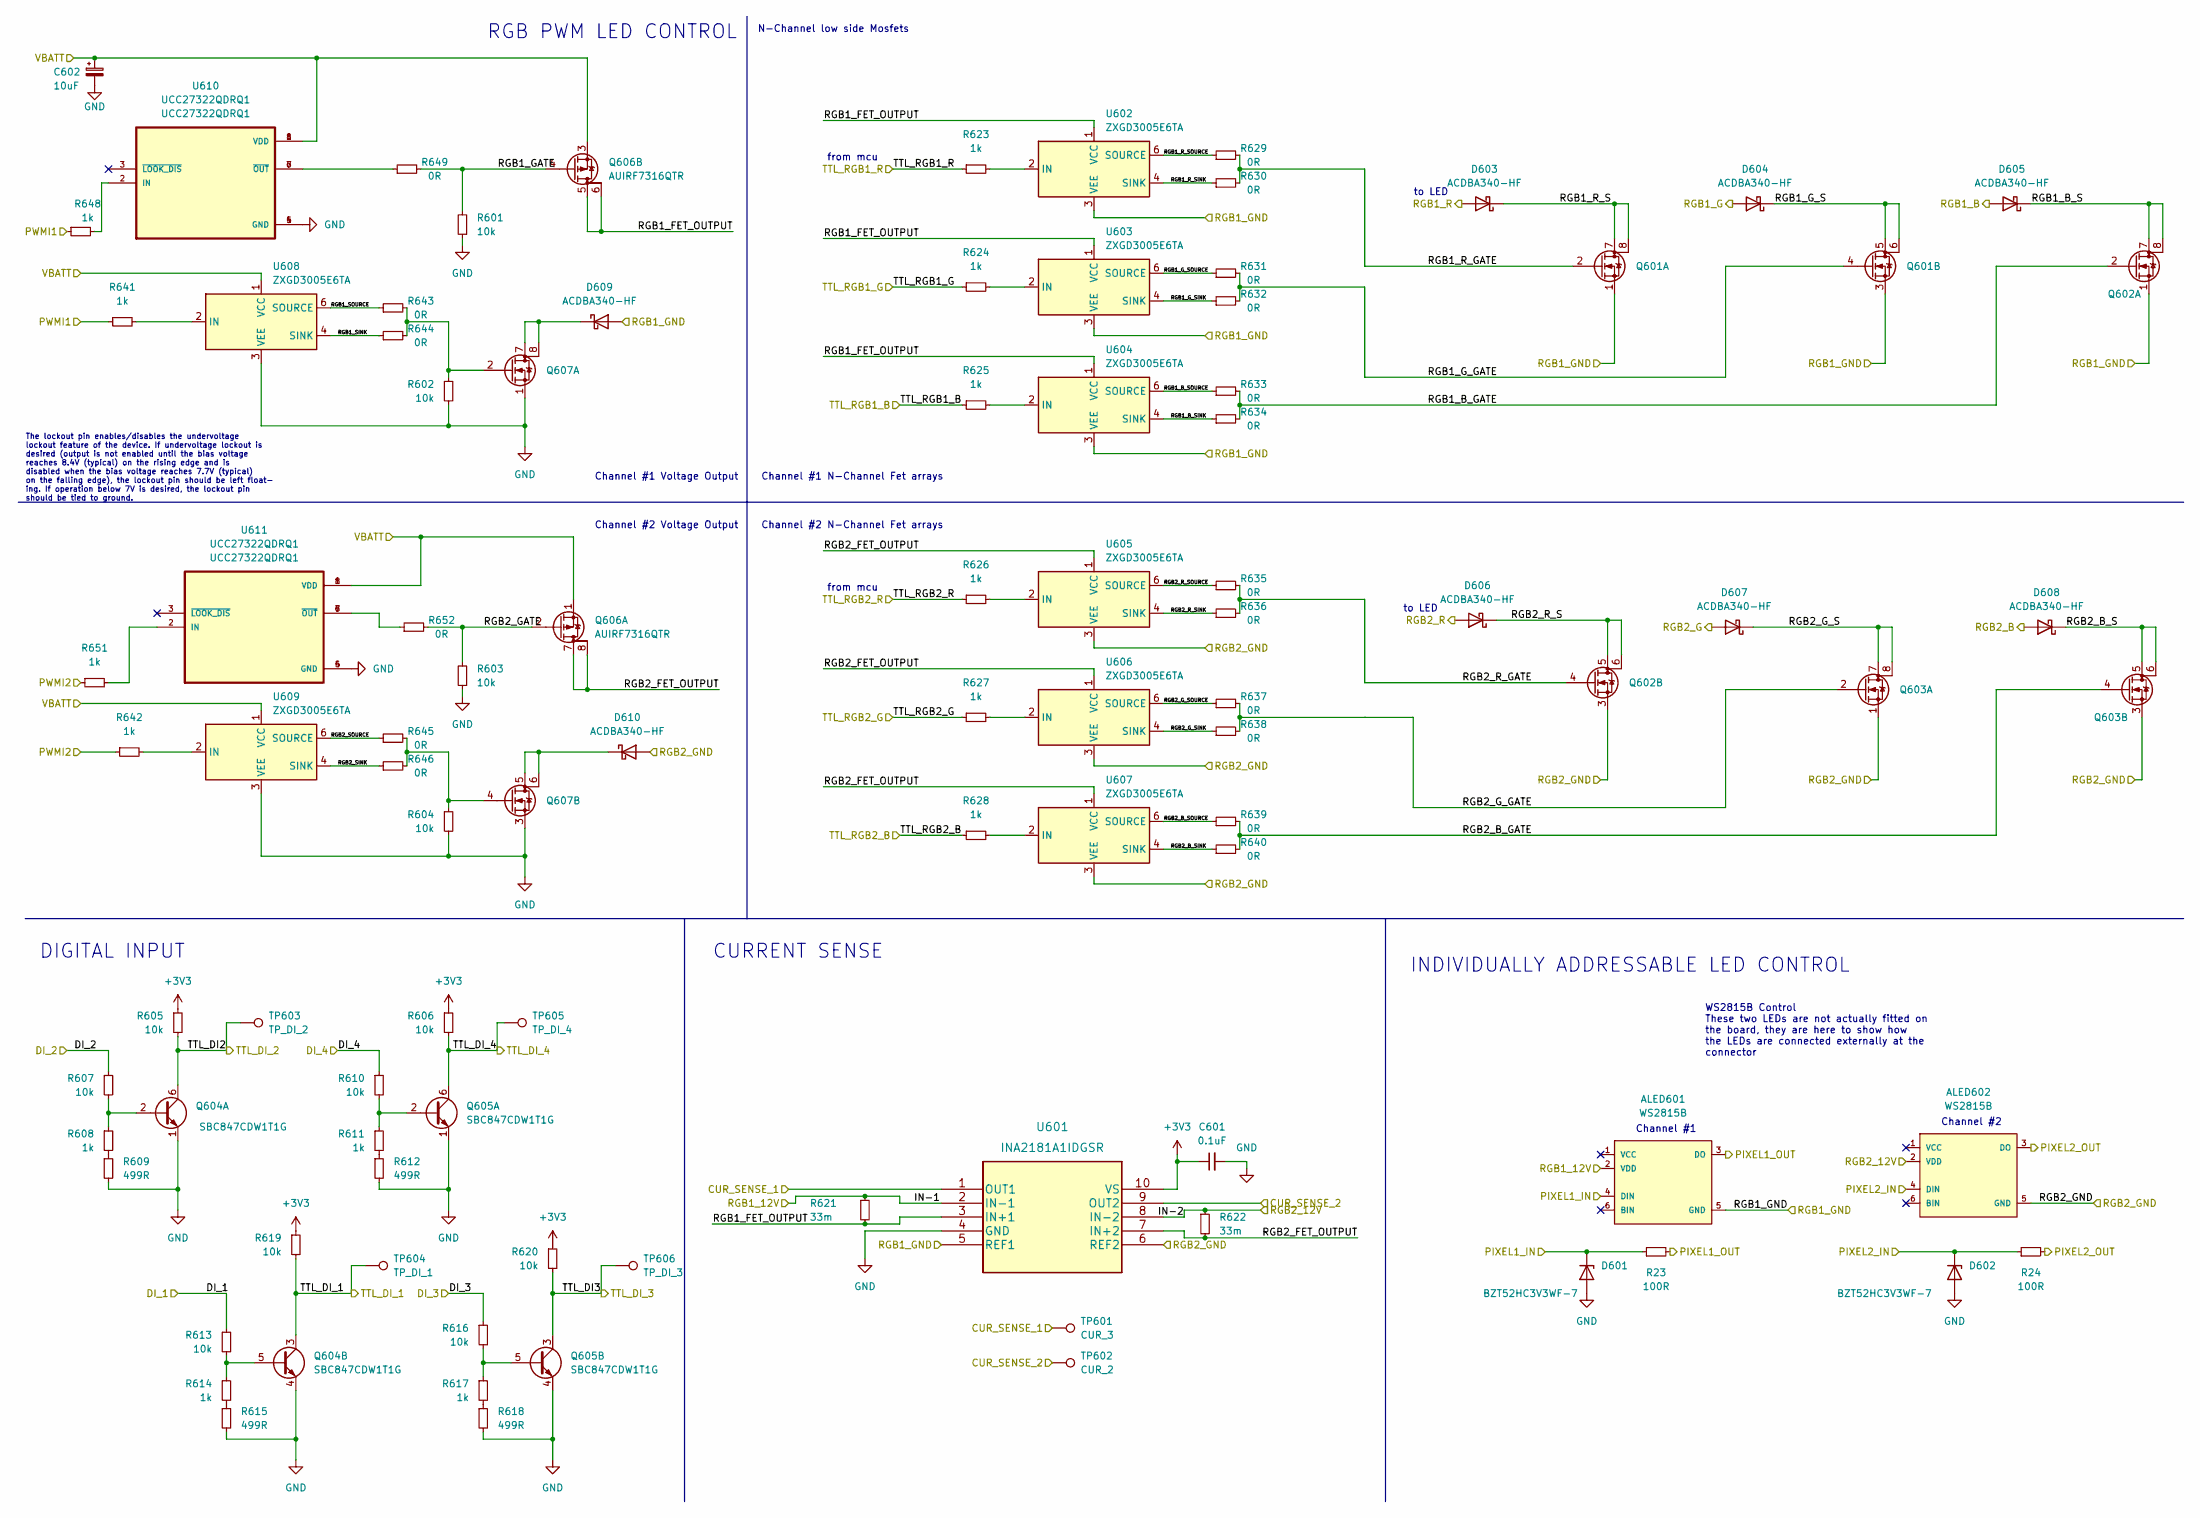
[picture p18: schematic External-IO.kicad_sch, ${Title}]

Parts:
ALED601, ALED602: WS2815B; worldsemi-WS2815B-*; Digikey 47948-0001
C601: 0.1uF; C_0402_1005Metric; Digikey CGA2B1X7R1C104M050BC
C602: 10uF; CP_Elec_5x5.9; Digikey 106AXZ035M
D601, D602: BZT52HC3V3WF-7; D_SOD-123F; Digikey BZT52HC3V3WF-7
D603, D604, D605, D606, D607, D608, D609, D610: ACDBA340-HF; D_SMA; Digikey ACDBA340-HF
Q601, Q602, Q603, Q607: SQ4282EY-T1_BE3; SO-8_3.9x4.9mm_P1.27mm; Digikey SQ4282EY-T1_BE3
Q604, Q605: SBC847CDW1T1G; SOT-363_SC-70-6; Digikey SBC847CDW1T1G
Q606: AUIRF7316QTR; SO-8_3.9x4.9mm_P1.27mm; Digikey AUIRF7316QTR
R23, R24: 100R; R_2512_6332Metric
R601, R602, R603, R604: 10k; R_0805_2012Metric; Digikey RNCP0805FTD10K0
R605, R606, R607, R610, R613, R616, R619, R620: 10k; R_0402_1005Metric; Digikey RMCF0402JT10K0
R608, R611, R614, R617, R623, R624, R625, R626, R627, R628, R641, R642, R648, R651: 1k; R_0402_1005Metric; Digikey RMCF0402FT1K00
R609, R612, R615, R618: 499R; R_0402_1005Metric; Digikey RMCF0402FT499R
R621, R622: 33m; R_2512_6332Metric; Digikey CSM2512FT33L0
R629, R630, R631, R632, R633, R634, R635, R636, R637, R638, R639, R640, R643, R644, R645, R646, R649, R652: 0R; R_0805_2012Metric; Digikey RMCF0805ZT0R00
TP601: CUR_3; TestPoint_Pad_D1.0mm
TP602: CUR_2; TestPoint_Pad_D1.0mm
TP603: TP_DI_2; TestPoint_Pad_D1.0mm
TP604: TP_DI_1; TestPoint_Pad_D1.0mm
TP605: TP_DI_4; TestPoint_Pad_D1.0mm
TP606: TP_DI_3; TestPoint_Pad_D1.0mm
U601: INA2181A1IDGSR; VSSOP-10_3x3mm_P0.5mm; Digikey INA2181A1IDGSR
U602, U603, U604, U605, U606, U607, U608, U609: ZXGD3005E6TA; SOT-23-6; Digikey ZXGD3005E6TA
U610, U611: UCC27322QDRQ1; SOIC127P600X175-8N; Digikey UCC27322QDRQ1

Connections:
+3V3: C601.1, R605.1, R606.1, R619.1, R620.1, U601.10 (VS); also elsewhere on the board
/Connectors/DI_1: R613.1; also elsewhere on the board
/Connectors/DI_2: R607.1; also elsewhere on the board
/Connectors/DI_3: R616.1; also elsewhere on the board
/Connectors/DI_4: R610.1; also elsewhere on the board
/Connectors/PIXEL_1: ALED601.3 (DO), R23.2; also elsewhere on the board
/Connectors/PIXEL_2: ALED602.3 (DO), R24.2; also elsewhere on the board
/Connectors/RGB1_12V: ALED601.2 (VDD), R621.1, U601.2 (IN-1); also elsewhere on the board
/Connectors/RGB1_B: D605.2 (A); also elsewhere on the board
/Connectors/RGB1_G: D604.2 (A); also elsewhere on the board
/Connectors/RGB1_GND: ALED601.5 (GND), D609.2 (A), Q601.1 (S), Q601.3 (S), Q602.1 (S), U601.5 (REF1), U602.3 (VEE), U603.3 (VEE), U604.3 (VEE); also elsewhere on the board
/Connectors/RGB1_R: D603.2 (A); also elsewhere on the board
/Connectors/RGB2_12V: ALED602.2 (VDD), R622.1, U601.8 (IN-2); also elsewhere on the board
/Connectors/RGB2_B: D608.2 (A); also elsewhere on the board
/Connectors/RGB2_G: D607.2 (A); also elsewhere on the board
/Connectors/RGB2_GND: ALED602.5 (GND), D610.2 (A), Q602.3 (S), Q603.1 (S), Q603.3 (S), U601.6 (REF2), U605.3 (VEE), U606.3 (VEE), U607.3 (VEE); also elsewhere on the board
/Connectors/RGB2_R: D606.2 (A); also elsewhere on the board
/Connectors/VBATT: C602.1, Q606.1 (S), Q606.3 (S), U608.1 (VCC), U609.1 (VCC), U610.1 (VDD), U610.8 (VDD), U611.1 (VDD), U611.8 (VDD); also elsewhere on the board
/ESP32-S3/GPIO3: Q605.3 (C509), R620.2, TP606.1; also elsewhere on the board
/ESP32-S3/GPIO4: Q605.6 (C1), R606.2, TP605.1; also elsewhere on the board
/ESP32-S3/GPIO5: Q604.3 (C509), R619.2, TP604.1; also elsewhere on the board
/ESP32-S3/GPIO6: Q604.6 (C1), R605.2, TP603.1; also elsewhere on the board
/ESP32-S3/GPIO8: ALED602.4 (DIN), D602.1 (K), R24.1; also elsewhere on the board
/ESP32-S3/GPIO9: ALED601.4 (DIN), D601.1 (K), R23.1; also elsewhere on the board
/ESP32-S3/GPIO13: R628.1; also elsewhere on the board
/ESP32-S3/GPIO14: R627.1; also elsewhere on the board
/ESP32-S3/GPIO15: R626.1; also elsewhere on the board
/ESP32-S3/GPIO16: R625.1; also elsewhere on the board
/ESP32-S3/GPIO17: R624.1; also elsewhere on the board
/ESP32-S3/GPIO_18: R623.1; also elsewhere on the board
/ESP32-S3/RGB1_CURRENT_SENSE: TP601.1, U601.1 (OUT1); also elsewhere on the board
/ESP32-S3/RGB1_PWM: R641.1, R648.1; also elsewhere on the board
/ESP32-S3/RGB2_CURRENT_SENSE: TP602.1, U601.9 (OUT2); also elsewhere on the board
/ESP32-S3/RGB2_PWM: R642.1, R651.1; also elsewhere on the board
/External-IO/RGB1_B_GATE: Q602.2 (G), R633.2, R634.2
/External-IO/RGB1_B_S: D605.1 (K), Q602.7 (D), Q602.8 (D)
/External-IO/RGB1_B_SINK: R634.1, U604.4 (SINK)
/External-IO/RGB1_B_SOURCE: R633.1, U604.6 (SOURCE)
/External-IO/RGB1_FET_OUTPUT: Q606.5 (D), Q606.6 (G), R621.2, U601.3 (IN+1), U602.1 (VCC), U603.1 (VCC), U604.1 (VCC)
/External-IO/RGB1_GATE: Q606.4 (G), R601.2, R649.2
/External-IO/RGB1_G_GATE: Q601.4 (G), R631.2, R632.2
/External-IO/RGB1_G_S: D604.1 (K), Q601.5 (D), Q601.6 (D)
/External-IO/RGB1_G_SINK: R632.1, U603.4 (SINK)
/External-IO/RGB1_G_SOURCE: R631.1, U603.6 (SOURCE)
/External-IO/RGB1_R_GATE: Q601.2 (G), R629.2, R630.2
/External-IO/RGB1_R_S: D603.1 (K), Q601.7 (D), Q601.8 (D)
/External-IO/RGB1_R_SINK: R630.1, U602.4 (SINK)
/External-IO/RGB1_R_SOURCE: R629.1, U602.6 (SOURCE)
/External-IO/RGB1_SINK: R644.1, U608.4 (SINK)
/External-IO/RGB1_SOURCE: R643.1, U608.6 (SOURCE)
/External-IO/RGB2_B_GATE: Q603.4 (G), R639.2, R640.2
/External-IO/RGB2_B_S: D608.1 (K), Q603.5 (D), Q603.6 (D)
/External-IO/RGB2_B_SINK: R640.1, U607.4 (SINK)
/External-IO/RGB2_B_SOURCE: R639.1, U607.6 (SOURCE)
/External-IO/RGB2_FET_OUTPUT: Q606.7 (D), Q606.8 (G), R622.2, U601.7 (IN+2), U605.1 (VCC), U606.1 (VCC), U607.1 (VCC)
/External-IO/RGB2_GATE: Q606.2 (G), R603.2, R652.2
/External-IO/RGB2_G_GATE: Q603.2 (G), R637.2, R638.2
/External-IO/RGB2_G_S: D607.1 (K), Q603.7 (D), Q603.8 (D)
/External-IO/RGB2_G_SINK: R638.1, U606.4 (SINK)
/External-IO/RGB2_G_SOURCE: R637.1, U606.6 (SOURCE)
/External-IO/RGB2_R_GATE: Q602.4 (G), R635.2, R636.2
/External-IO/RGB2_R_S: D606.1 (K), Q602.5 (D), Q602.6 (D)
/External-IO/RGB2_R_SINK: R636.1, U605.4 (SINK)
/External-IO/RGB2_R_SOURCE: R635.1, U605.6 (SOURCE)
/External-IO/RGB2_SINK: R646.1, U609.4 (SINK)
/External-IO/RGB2_SOURCE: R645.1, U609.6 (SOURCE)
GND: C601.2, C602.2, D601.2 (A), D602.2 (A), Q604.1 (E1), Q604.4 (E2), Q605.1 (E1), Q605.4 (E2), Q607.1 (S), Q607.3 (S), R601.1, R602.2, R603.1, R604.2, R609.2, R612.2, R615.2, R618.2, U601.4 (GND), U608.3 (VEE), U609.3 (VEE), U610.4 (GND), U610.5 (GND), U611.4 (GND), U611.5 (GND); also elsewhere on the board
unnamed: D609.1 (K), Q607.7 (D), Q607.8 (D)
unnamed: D610.1 (K), Q607.5 (D), Q607.6 (D)
unnamed: Q604.2 (B1), R607.2, R608.1
unnamed: Q604.5 (B2), R613.2, R614.1
unnamed: Q605.2 (B1), R610.2, R611.1
unnamed: Q605.5 (B2), R616.2, R617.1
unnamed: Q607.2 (G), R602.1, R643.2, R644.2
unnamed: Q607.4 (G), R604.1, R645.2, R646.2
unnamed: R608.2, R609.1
unnamed: R611.2, R612.1
unnamed: R614.2, R615.1
unnamed: R617.2, R618.1
unnamed: R623.2, U602.2 (IN)
unnamed: R624.2, U603.2 (IN)
unnamed: R625.2, U604.2 (IN)
unnamed: R626.2, U605.2 (IN)
unnamed: R627.2, U606.2 (IN)
unnamed: R628.2, U607.2 (IN)
unnamed: R641.2, U608.2 (IN)
unnamed: R642.2, U609.2 (IN)
unnamed: R648.2, U610.2 (IN)
unnamed: R649.1, U610.6 (~OUT), U610.7 (~OUT)
unnamed: R651.2, U611.2 (IN)
unnamed: R652.1, U611.6 (~OUT), U611.7 (~OUT)

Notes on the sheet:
to LED
Channel #2
DIGITAL INPUT
from mcu
Channel #1 N-Channel Fet arrays
The lockout pin enables/disables the undervoltage lockout feature of the device. If undervoltage lockout is desired (output is not enabled until the bias voltage reaches 8.4V (typical) on the rising edge and is disabled when the bias voltage reaches 7.7V (typical) on the falling edge), the lockout 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
WS2815B Control These two LEDs are not actually fitted on the board, they are here to show how the LEDs are connected externally at the connector
RGB PWM LED CONTROL
Channel #2 Voltage Output
Channel #1 Voltage Output
CURRENT SENSE
N-Channel low side Mosfets
Channel #2 N-Channel Fet arrays
INDIVIDUALLY ADDRESSABLE LED CONTROL
Channel #1

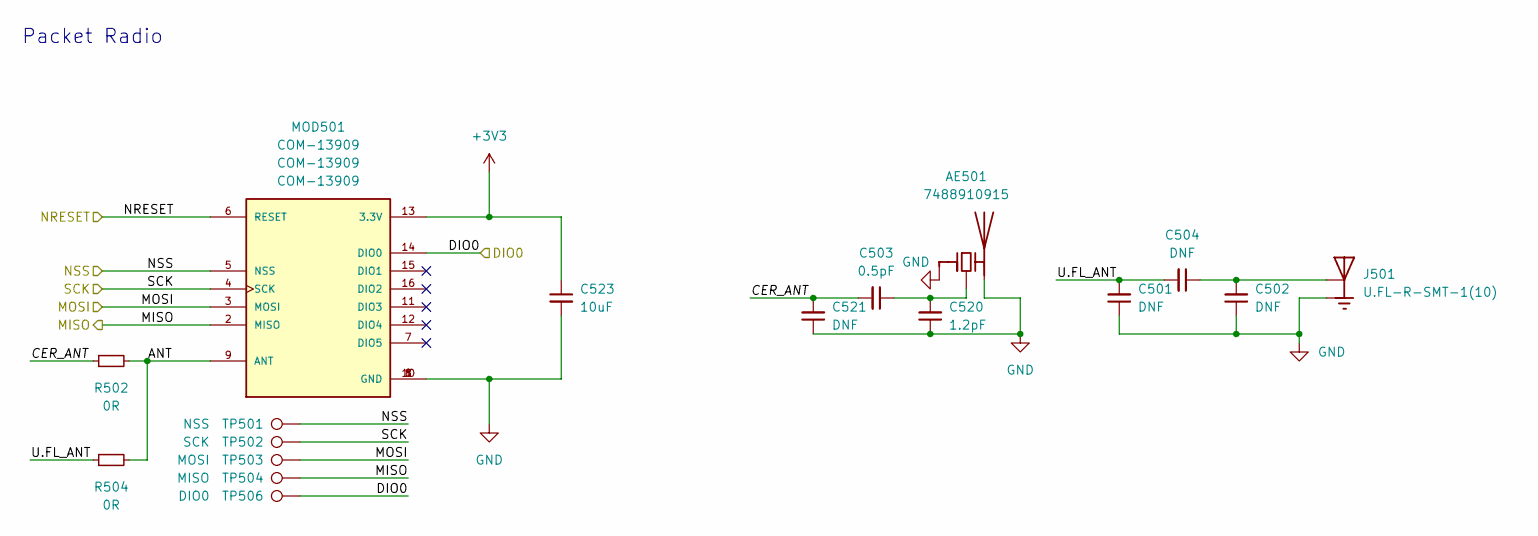
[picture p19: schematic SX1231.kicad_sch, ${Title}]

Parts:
AE501: 7488910915; Digikey 7488910915
C501, C502, C504, C521: DNF; C_0402_1005Metric
C503: 0.5pF; C_0402_1005Metric; Digikey C0402C508D3GAC7867
C520: 1.2pF; C_0402_1005Metric; Digikey C0402C129D3GAC7867
C523: 10uF; C_0805_2012Metric; Digikey GRT21BC81A106KE01L
J501: U.FL-R-SMT-1(10); HRS_U.FL-R-SMT-1(10); Digikey U.FL-R-SMT-1(10)
MOD501: COM-13909; HOPERF_RFM9XW_SMD; MPN2 COM-13909; Digikey COM-13909
R502, R504: 0R; R_0402_1005Metric; Digikey RC0402JR-070RP
TP501: NSS; TestPoint_Pad_D1.0mm
TP502: SCK; TestPoint_Pad_D1.0mm
TP503: MOSI; TestPoint_Pad_D1.0mm
TP504: MISO; TestPoint_Pad_D1.0mm
TP506: DIO0; TestPoint_Pad_D1.0mm

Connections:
+3V3: C523.1, MOD501.13 (3.3V); also elsewhere on the board
/CS1: MOD501.5 (NSS), TP501.1; also elsewhere on the board
/MISO: MOD501.2 (MISO), TP504.1; also elsewhere on the board
/MOSI: MOD501.3 (MOSI), TP503.1; also elsewhere on the board
/SCLK: MOD501.4 (SCK), TP502.1; also elsewhere on the board
/SX1231/ANT: MOD501.9 (ANT), R502.2, R504.2
/SX1231/CER_ANT: C503.2, C521.2, R502.1
/SX1231/DIO0: MOD501.14 (DIO0), TP506.1; also elsewhere on the board
/SX1231/NRESET: MOD501.6 (RESET); also elsewhere on the board
/SX1231/U.FL_ANT: C501.2, C504.2, R504.1
GND: AE501.1 (PCB_Trace), AE501.2 (PCB_Trace), C501.1, C502.1, C520.1, C521.1, C523.2, J501.1, J501.3, MOD501.1 (GND), MOD501.8 (GND), MOD501.10 (GND); also elsewhere on the board
unnamed: AE501.3 (FEED), C503.1, C520.2
unnamed: C502.2, C504.1, J501.2

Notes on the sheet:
Packet Radio

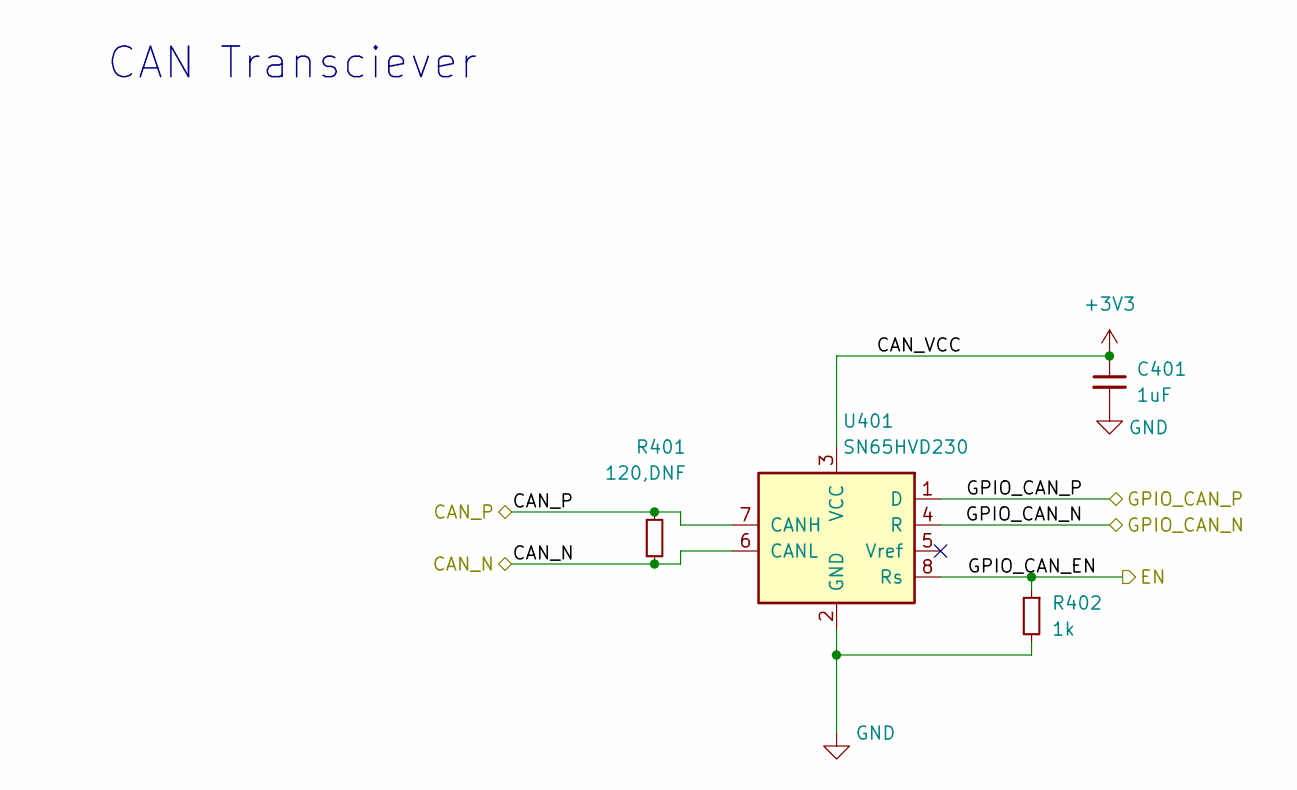
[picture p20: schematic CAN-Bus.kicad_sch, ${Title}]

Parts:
C401: 1uF; C_0402_1005Metric; Digikey CGA2B1X7T0G105M050BC
R401: 120,DNF; R_0805_2012Metric; Digikey RMCF0805JT120R
R402: 1k; R_0402_1005Metric; Digikey RMCF0402FT1K00
U401: SN65HVD230; SOIC-8_3.9x4.9mm_P1.27mm; Digikey SN65HVD230D

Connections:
+3V3: C401.1, U401.3 (VCC); also elsewhere on the board
/CAN_EN: R402.1, U401.8 (Rs); also elsewhere on the board
/CAN_H: R401.2, U401.7 (CANH); also elsewhere on the board
/CAN_L: R401.1, U401.6 (CANL); also elsewhere on the board
/GPIO_CAN_N: U401.4 (R); also elsewhere on the board
/GPIO_CAN_P: U401.1 (D); also elsewhere on the board
GND: C401.2, R402.2, U401.2 (GND); also elsewhere on the board

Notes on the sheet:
CAN Transciever

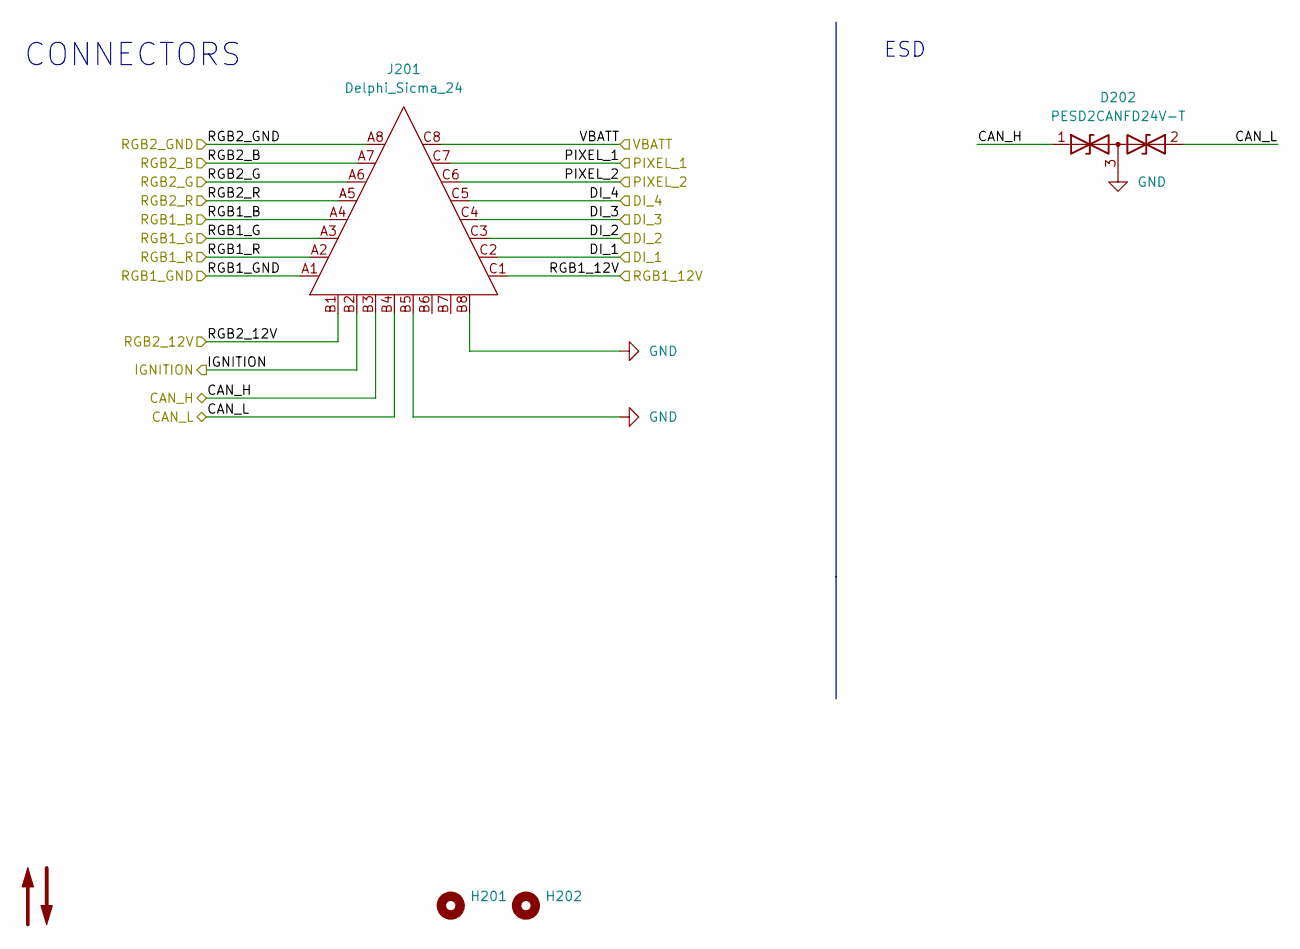
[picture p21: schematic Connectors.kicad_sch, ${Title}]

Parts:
D202: PESD2CANFD24V-T; SOT-23; Digikey PESD2CANFD24V-T
H201, H202: MountingHole_Pad; MountingHole_2.7mm_M2.5
J201: Delphi_Sicma_24; Delphi_Sicma_24_Black

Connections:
/CAN_H: D202.1 (A1), J201.B3; also elsewhere on the board
/CAN_L: D202.2 (A2), J201.B4; also elsewhere on the board
/Connectors/DI_1: J201.C2; also elsewhere on the board
/Connectors/DI_2: J201.C3; also elsewhere on the board
/Connectors/DI_3: J201.C4; also elsewhere on the board
/Connectors/DI_4: J201.C5; also elsewhere on the board
/Connectors/IGNITION: J201.B2; also elsewhere on the board
/Connectors/PIXEL_1: J201.C7; also elsewhere on the board
/Connectors/PIXEL_2: J201.C6; also elsewhere on the board
/Connectors/RGB1_12V: J201.C1; also elsewhere on the board
/Connectors/RGB1_B: J201.A4; also elsewhere on the board
/Connectors/RGB1_G: J201.A3; also elsewhere on the board
/Connectors/RGB1_GND: J201.A1; also elsewhere on the board
/Connectors/RGB1_R: J201.A2; also elsewhere on the board
/Connectors/RGB2_12V: J201.B1; also elsewhere on the board
/Connectors/RGB2_B: J201.A7; also elsewhere on the board
/Connectors/RGB2_G: J201.A6; also elsewhere on the board
/Connectors/RGB2_GND: J201.A8; also elsewhere on the board
/Connectors/RGB2_R: J201.A5; also elsewhere on the board
/Connectors/VBATT: J201.C8; also elsewhere on the board
GND: D202.3 (common), J201.B5, J201.B8; also elsewhere on the board

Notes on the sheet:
ESD
CONNECTORS

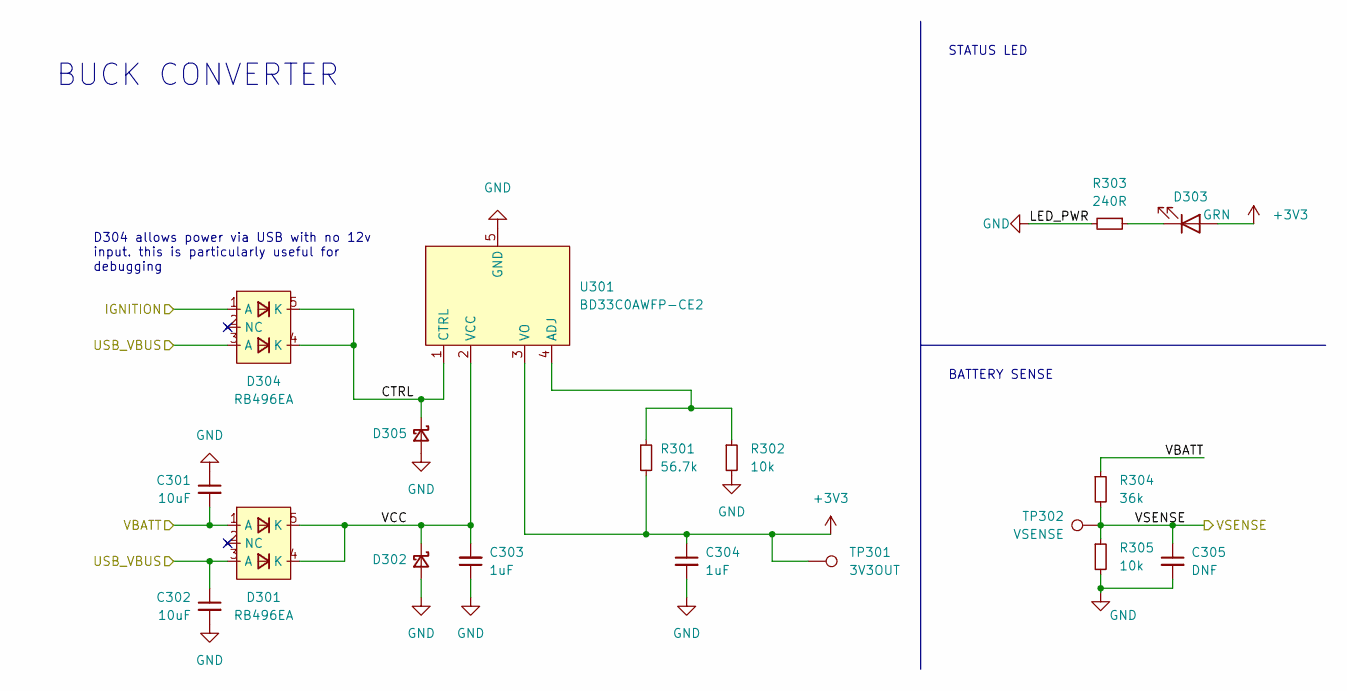
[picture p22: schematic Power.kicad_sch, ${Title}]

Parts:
C301, C302: 10uF; C_0805_2012Metric; Digikey GRT21BC81A106KE01L
C303, C304: 1uF; C_0805_2012Metric; Digikey CL21B105KOF4PNE
C305: DNF; C_0603_1608Metric
D301, D304: RB496EA; SOT-23-5; Digikey RB496EA
D302, D305: BYS10-45HE3_A/H; D_SMA; Digikey BYS10-45HE3_A/H
D303: GRN; LED_0603_1608Metric; Digikey LTST-C191KGKT
R301: 56.7k; R_0805_2012Metric; Digikey RMCF0805FT57K6
R302: 10k; R_0805_2012Metric; Digikey RNCP0805FTD10K0
R303: 240R; R_0603_1608Metric; Digikey RMCF0603JT240R
R304: 36k; R_0603_1608Metric
R305: 10k; R_0603_1608Metric
TP301: 3V3OUT; TestPoint_Pad_D1.0mm
TP302: VSENSE; TestPoint_Pad_D1.0mm
U301: BD33C0AWFP-CE2; Digikey BD33C0AWFP-CE2

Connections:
+3V3: C304.1, D303.2 (A), R301.2, TP301.1, U301.3 (VO); also elsewhere on the board
/Connectors/IGNITION: D304.1 (A); also elsewhere on the board
/Connectors/VBATT: C301.2, D301.1 (A), R304.1; also elsewhere on the board
/Power/CTRL: D304.4 (K), D304.5 (K), D305.1 (K), U301.1 (CTRL)
/Power/USB_VBUS: C302.1, D301.3 (A), D304.3 (A)
/Power/VCC: C303.2, D301.4 (K), D301.5 (K), D302.1 (K), U301.2 (VCC)
/VSENSE: C305.1, R304.2, R305.1, TP302.1; also elsewhere on the board
GND: C301.1, C302.2, C303.1, C304.2, C305.2, D302.2 (A), D305.2 (A), R302.2, R303.2, R305.2, U301.5 (GND); also elsewhere on the board
unnamed: D303.1 (K), R303.1
unnamed: R301.1, R302.1, U301.4 (ADJ)

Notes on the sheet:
STATUS LED
D304 allows power via USB with no 12v input. this is particularly useful for debugging
BUCK CONVERTER
BATTERY SENSE

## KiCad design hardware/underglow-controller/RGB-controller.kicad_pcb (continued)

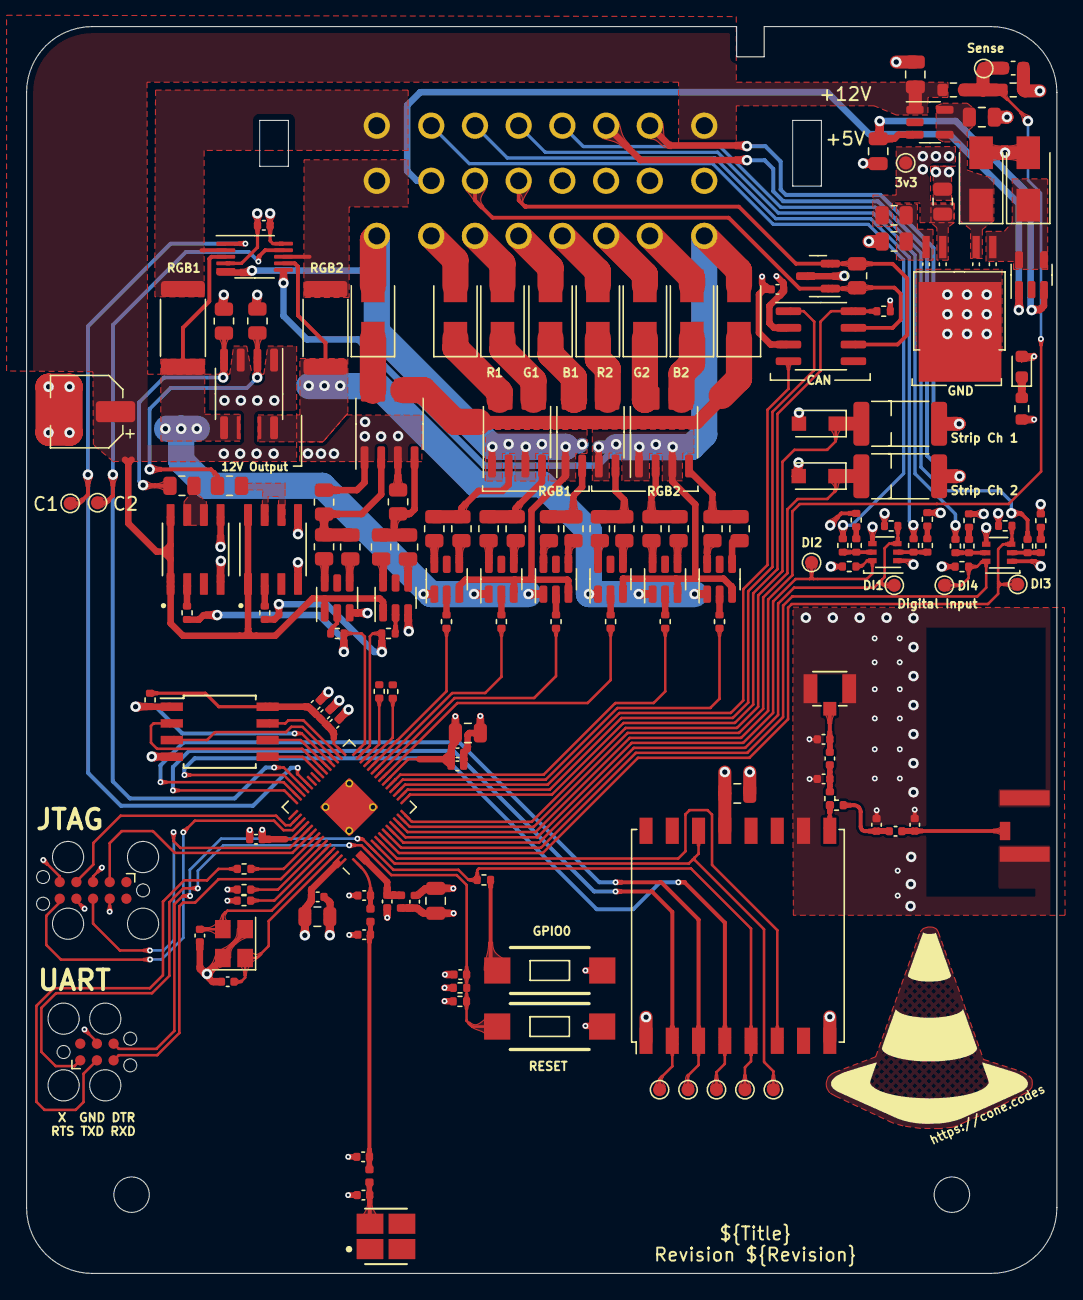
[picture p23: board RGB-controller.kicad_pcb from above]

Board: 4 copper layers, 78.5 x 95.0 mm, 172 parts (0 on the bottom side), 140 nets.

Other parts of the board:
Enclosure_Bottom: Enclosure_Bottom
Enclosure_Top: Enclosure_Top

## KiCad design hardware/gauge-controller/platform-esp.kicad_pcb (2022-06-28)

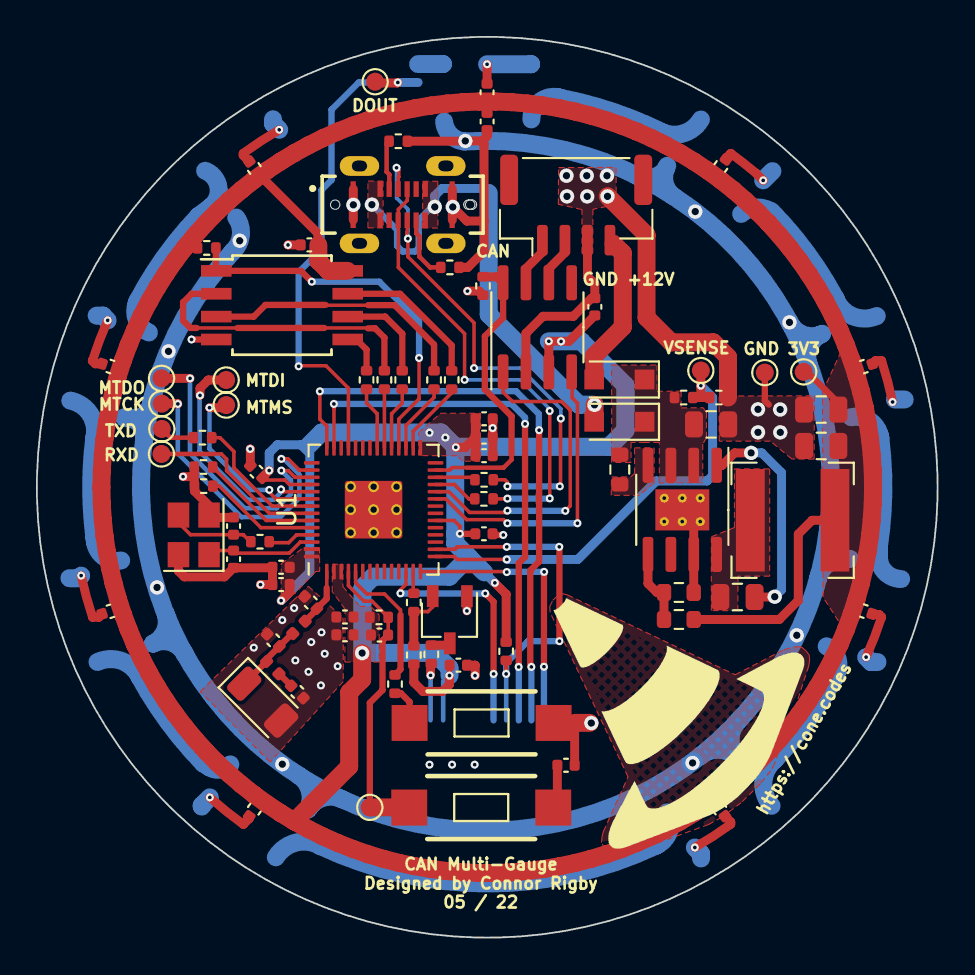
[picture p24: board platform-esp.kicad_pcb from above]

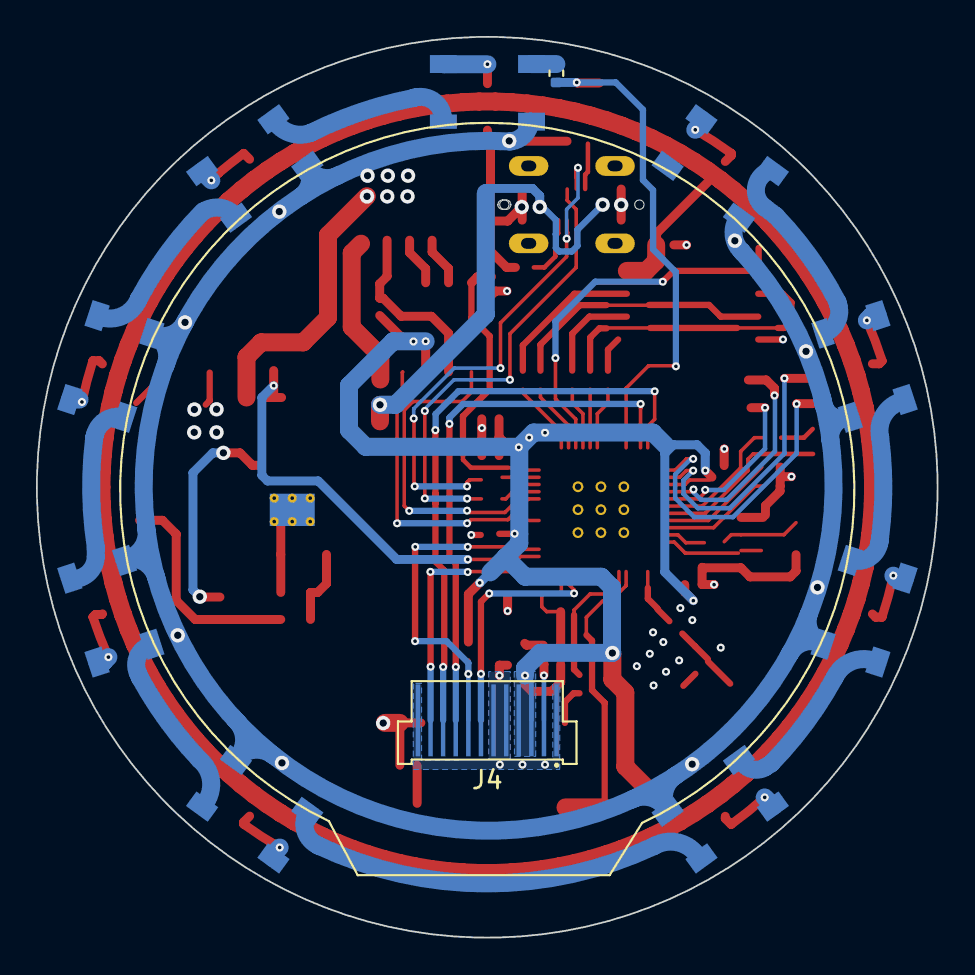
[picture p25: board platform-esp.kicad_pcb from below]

Board: 4 copper layers, 50.0 x 50.0 mm, 97 parts (11 on the bottom side), 80 nets.

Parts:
AE1: Antenna_Shield; Johanson_2450AT18x100
C1, C7, C12, C18, C28, C30, C31, C32, C33, C34, C35, C36, C37, C38: 1uF; C_0402_1005Metric
C2, C13, C29: 10uF; C_0402_1005Metric
C3, C4, C5, C14, C15: C_Small; C_0402_1005Metric
C6, C8, C9, C11, C16, C17, C19: 0.1uF; C_0402_1005Metric
C10: 10uF; C_0805_2012Metric
C20: 0.1uF; C_0805_2012Metric
C21, C22: 22uF; C_0805_2012Metric
D1, D11: D_Small; D_SOD-123F
D2, D3, D4, D5, D6, D7, D8, D9, D10: WS2812B; LED_WS2812B_PLCC4_5.0x5.0mm_P3.2mm
J1: USB4120-03-C_REVA; GCT_USB4120-03-C_REVA
J2: PWR_CAN; JST_GH_BM04B-GHS-TBT_1x04-1MP_P1.25mm_Vertical
J4: Conn_01x12; GC9A01_disp
L1, L2: L_Small; L_0402_1005Metric
L3: 6.8uh; L_Bourns-SRN6028
Q1: Q_NPN_EBC; TSOT-23
R1, R12, R13, R15, R16, R17, R18, R22: 10k; R_0402_1005Metric
R2, R4, R5, R6, R7, R9, R10, R11, R25: 0; R_0402_1005Metric
R3: 499; R_0402_1005Metric
R8, R27: 100k; R_0402_1005Metric
R14: 36k; R_0402_1005Metric
R19: 100k; R_0603_1608Metric
R20: 31k6; R_0603_1608Metric
R21: 10k2; R_0603_1608Metric
R23, R24: 51k; R_0402_1005Metric
R26: 10R; R_0402_1005Metric
SW1, SW2: SW_Push; SW_RS-032G05A3-SMRT
TP1: CHIP_PU; TestPoint_Pad_D1.0mm
TP2: VBAT_SENSE; TestPoint_Pad_D1.0mm
TP3: MTCK; TestPoint_Pad_D1.0mm
TP4: MTMS; TestPoint_Pad_D1.0mm
TP5: NEO_OUT; TestPoint_Pad_D1.0mm
TP6: MTDO; TestPoint_Pad_D1.0mm
TP7: MTDI; TestPoint_Pad_D1.0mm
TP8: TXD; TestPoint_Pad_D1.0mm
TP9: RXD; TestPoint_Pad_D1.0mm
TP10, TP11: 3V3OUT; TestPoint_Pad_D1.0mm
U1: ESP32-S3R2; QFN-56
U2: SN65HVD230; SOIC-8_3.9x4.9mm_P1.27mm
U3: W25Q128JVS; SOIC-8W_5.3x5.3mm_P1.27mm
U5: ADP2303ARDZ-3.3; SOIC-8-1EP_3.9x4.9mm_P1.27mm_EP2.29x3mm_ThermalVias
Y1: 40MHZ; Crystal_SMD_3225-4Pin_3.2x2.5mm

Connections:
+3V3: C1.1, C2.1, C6.1, C7.1, C8.1, C9.1, C11.1, C12.1, C13.1, C16.1, C17.1, C19.2, C21.1, C22.1, C28.1, C29.1, C30.1, C31.1, C32.1, C33.1, C34.1, C35.1, C36.1, C37.1, C38.1, J4.3, J4.4, L3.2, R1.2, R8.1, R20.1, R22.2, R27.1, TP11.1, U1.2 (VDD3P3), U1.3 (VDD3P3), U1.20 (VDD3P3_RTC), U1.29 (VDD_SPI), U1.46 (VDD3P3_CPU), U1.55 (VDDA1), U1.56 (VDDA2), U2.3 (VCC), U3.8 (VCC)
/BL: R18.1, U1.13 (GPIO8)
/BST: C20.1, U5.1 (BST)
/CAN_DRV_N: J2.2, U2.6 (CANL)
/CAN_DRV_P: J2.1, U2.7 (CANH)
/CAN_EN: R12.1, U1.27 (GPIO21), U2.8 (Rs)
/CAN_N: U1.23 (GPIO17), U2.4 (R)
/CAN_P: U1.24 (GPIO18), U2.1 (D)
/CC1: J1.A5 (CC1), R23.1
/CC2: J1.B5 (CC2), R24.1
/CHIP_PU: C19.1, R1.1, SW1.1, TP1.1, U1.4 (CHIP_PU)
/CHIP_PU_BOOTSTRAP: C18.1, SW1.2
/DC: J4.7, U1.12 (GPIO7)
/EXT_VIN: D1.2 (A), J2.4
/FB: R20.2, R21.1, U5.5 (FB)
/FSPICLK: J4.9, U1.41 (GPIO36)
/FSPICS0: J4.8, R27.2, U1.16 (GPIO11)
/FSPIQ: J4.10, U1.42 (GPIO37)
/GPIO0: R13.1, U1.5 (GPIO0)
/GPIO0_BOOTSTRAP: R13.2, SW2.1
/GPIO9: J4.11, U1.14 (GPIO9)
/GPIO10: R14.2, R16.1, TP2.1, U1.15 (GPIO10)
/GPIO34: R25.1, TP5.1, U1.39 (GPIO34)
/GPIO45: R15.1, U1.51 (GPIO45)
/GPIO46: R17.1, U1.52 (GPIO46)
/GPIO_USB_D_N: R4.1, U1.25 (GPIO19)
/GPIO_USB_D_P: R5.1, U1.26 (GPIO20)
/LCD_BL_DIV: Q1.2 (B), R18.2, R22.1
/LCD_LEDK: J4.2, R26.1
/LNA_IN: C3.2, L1.1, U1.1 (LNA_IN)
/MCU_SPICLK: R9.2, U1.33 (SPICLK)
/MCU_SPICS0: R8.2, U1.32 (SPICS0), U3.1 (~CS)
/MCU_SPID: R11.2, U1.35 (SPID)
/MCU_SPIHD: R6.2, U1.30 (SPIHD)
/MCU_SPIQ: R10.2, U1.34 (SPIQ)
/MCU_SPIWP: R7.2, U1.31 (SPIWP)
/MCU_U0TXD: R3.2, U1.49 (U0TXD)
/MCU_XTAL_N: R2.2, U1.53 (XTAL_N)
/MTCK: TP3.1, U1.44 (MTCK)
/MTDI: TP7.1, U1.47 (MTDI)
/MTDO: TP6.1, U1.45 (MTDO)
/MTMS: TP4.1, U1.48 (MTMS)
/PGOOD: R19.2, U5.4 (PGOOD)
/Q_LEDK: Q1.3 (C), R26.2
/RF_ANT: AE1.1 (A), C4.2, L1.2, L2.1
/SPICLK: R9.1, U3.6 (CLK)
/SPID: R11.1, U3.5 (DI(IO0))
/SPIHD: R6.1, U3.7 (IO3)
/SPIQ: R10.1, U3.2 (DO(IO1))
/SPIWP: R7.1, U3.3 (IO2)
/SW: C20.2, L3.1, U5.8 (SW)
/U0RXD: TP9.1, U1.50 (U0RXD)
/U0TXD: R3.1, TP8.1
/USB_D_N: J1.A7 (D1-), J1.B7 (D2-), R4.2
/USB_D_P: J1.A6 (D1+), J1.B6 (D2+), R5.2
/USB_VBUS: D11.2 (A), J1.A4 (VBUS_A), J1.A9 (VBUS_A), J1.B4 (VBUS_B), J1.B9 (VBUS_B)
/VIN: C10.2, D1.1 (K), D11.1 (K), R14.1, R19.1, U5.2 (Vin), U5.3 (EN)
/XTAL_N: C15.1, R2.1, Y1.3
/XTAL_P: C14.1, U1.54 (XTAL_P), Y1.1
GND: AE1.2 (Shield), C1.2, C2.2, C3.1, C4.1, C5.1, C6.2, C7.2, C8.2, C9.2, C10.1, C11.2, C12.2, C13.2, C14.2, C15.2, C16.2, C17.2, C18.2, C21.2, C22.2, C28.2, C29.2, D2.3 (VSS), D3.3 (VSS), D4.3 (VSS), D5.3 (VSS), D6.3 (VSS), D7.3 (VSS), D8.3 (VSS), D9.3 (VSS), D10.3 (VSS), J1.A1 (GND_A), J1.A12 (GND_A), J1.B1 (GND_B), J1.B12 (GND_B), J2.3, J4.1, J4.5, J4.6, J4.12, Q1.1 (E), R12.2, R15.2, R16.2, R17.2, R21.2, R23.2, R24.2, SW2.2, TP10.1, U1.57 (GND), U2.2 (GND), U3.4 (GND), U5.7 (GND), U5.9 (PADGND), Y1.2, Y1.4
unnamed: C5.2, L2.2
unnamed: C30.2, D2.1 (VDD)
unnamed: C31.2, D3.1 (VDD)
unnamed: C32.2, D4.1 (VDD)
unnamed: C33.2, D5.1 (VDD)
unnamed: C34.2, D6.1 (VDD)
unnamed: C35.2, D8.1 (VDD)
unnamed: C36.2, D9.1 (VDD)
unnamed: C37.2, D10.1 (VDD)
unnamed: C38.2, D7.1 (VDD)
unnamed: D2.2 (DOUT), D3.4 (DIN)
unnamed: D2.4 (DIN), R25.2
unnamed: D3.2 (DOUT), D4.4 (DIN)
unnamed: D4.2 (DOUT), D5.4 (DIN)
unnamed: D5.2 (DOUT), D6.4 (DIN)
unnamed: D6.2 (DOUT), D8.4 (DIN)
unnamed: D8.2 (DOUT), D9.4 (DIN)
unnamed: D7.4 (DIN), D10.2 (DOUT)
unnamed: D9.2 (DOUT), D10.4 (DIN)
unnamed: J1.S1 (SHIELD), J1.S2 (SHIELD), J1.S3 (SHIELD), J1.S4 (SHIELD)

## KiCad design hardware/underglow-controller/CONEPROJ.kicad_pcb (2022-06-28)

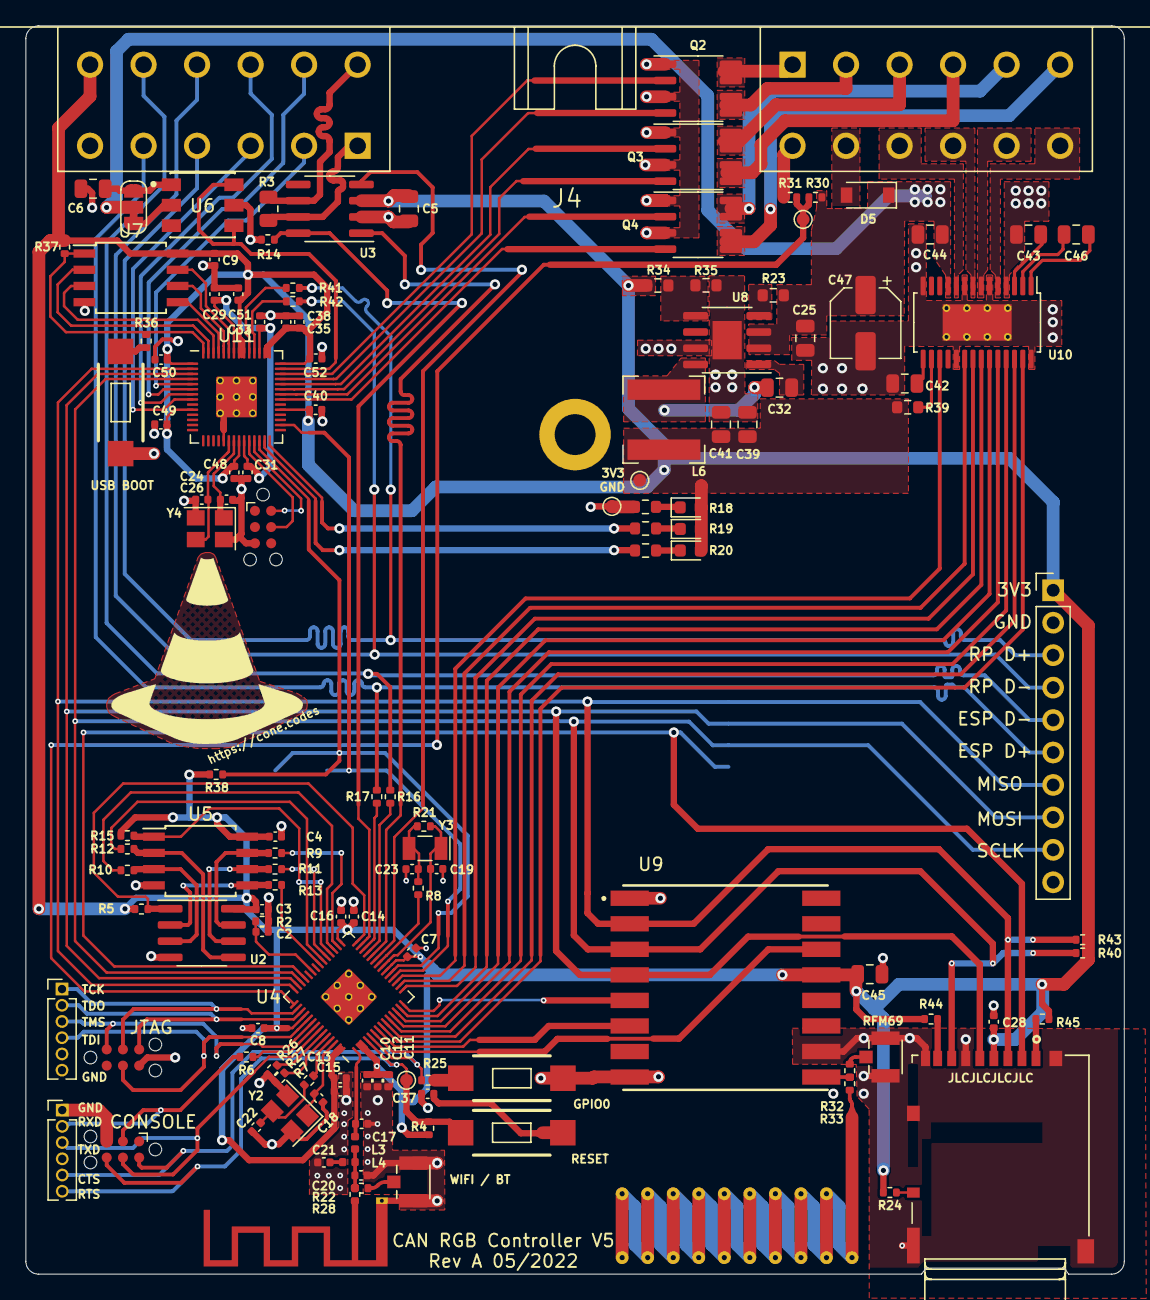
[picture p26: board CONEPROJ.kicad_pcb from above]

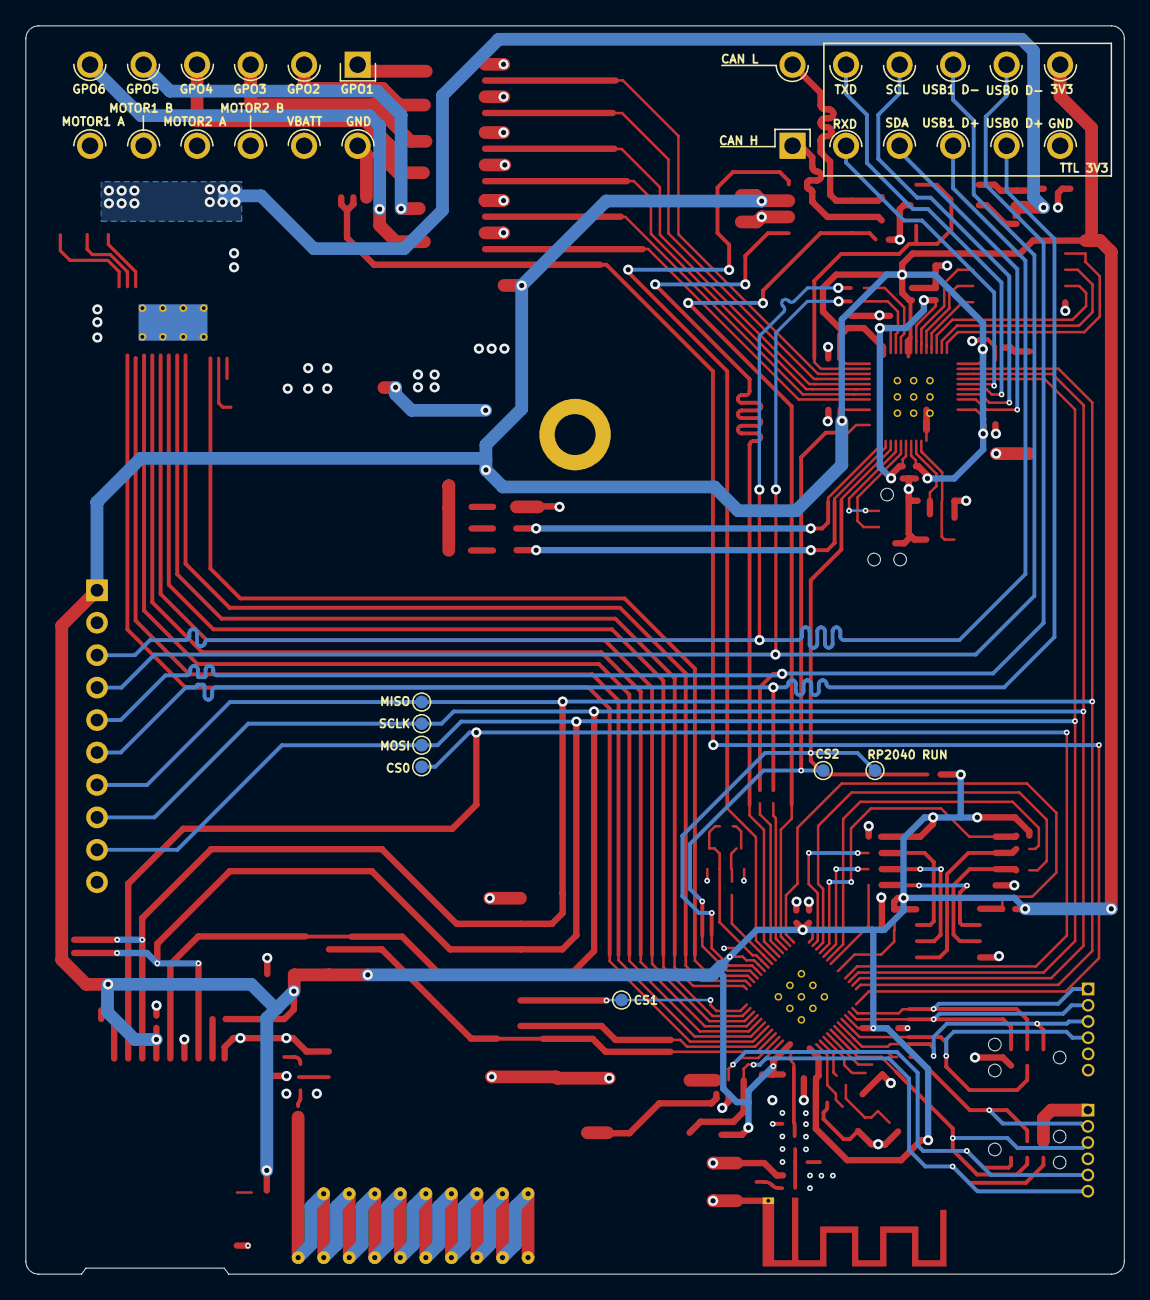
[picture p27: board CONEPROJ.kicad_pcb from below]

Board: 4 copper layers, 86.0 x 97.7 mm, 141 parts (7 on the bottom side), 128 nets.

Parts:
AE2: Antenna_Shield; Texas_SWRA117D_2.4GHz_Right
AE3: Antenna_Shield; Texas_SWRA416_868MHz_915MHz
C2, C11, C13, C16, C28, C33, C37, C38: 1uF; C_0402_1005Metric
C3, C4, C7, C8, C9, C10, C14, C29, C31, C35, C40, C48, C49, C50, C51, C52: 0.1uF; C_0402_1005Metric
C5, C25, C44, C45: 10uF; C_0805_2012Metric
C6, C32, C43: 0.1uF; C_0805_2012Metric
C12, C15: 10uF; C_0402_1005Metric
C17, C18, C19, C20, C21, C22, C23, C24, C26: C_Small; C_0402_1005Metric
C39, C41: 22uF; C_0805_2012Metric
C42: 0.47uF; C_0805_2012Metric
C46: 0.01uF; C_0805_2012Metric
C47: 10uF; CP_Elec_5x5.3
D2, D4: GRN; LED_0603_1608Metric
D3: RED; LED_0603_1608Metric
D5: D_Small; D_SOD-123
H1: MountingHole_Pad; MountingHole_3.2mm_M3_DIN965_Pad
J2, J7: U.FL-R-SMT-1(10); HRS_U.FL-R-SMT-1(10)
J3: DM3AT-SF-PEJM5; HRS_DM3AT-SF-PEJM5
J4: DTM1312PA12PBR008; TE_DTM1312PA12PBR008
J5: Conn_01x10; PinHeader_1x10_P2.54mm_Vertical
J6: CONSOLE; PinHeader_1x06_P1.27mm_Vertical
J8: JTAG; PinHeader_1x06_P1.27mm_Vertical
JP2: LED Voltage Select; SolderJumper-3_P1.3mm_Bridged12_RoundedPad1.0x1.5mm_NumberL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
L3, L4: L_Small; L_0402_1005Metric
L6: 6.8uh; L_Bourns-SRN6028
Q2, Q3, Q4: Q_Dual_NMOS_S1G1S2G2D2D2D1D1; SO-8_3.9x4.9mm_P1.27mm
R2: 442k; R_0402_1005Metric
R3: 120,DNF; R_0805_2012Metric
R4, R24, R25, R26, R27, R31, R38, R40, R43, R44, R45: 10k; R_0402_1005Metric
R5, R15, R37: 100k; R_0402_1005Metric
R6: 499R; R_0402_1005Metric
R7, R8, R9, R10, R11, R12, R13, R16, R17, R22, R28, R32, R33: 0R; R_0402_1005Metric
R14, R36: 1k; R_0402_1005Metric
R18, R19, R20: 240R; R_0603_1608Metric
R21: DNP; R_0402_1005Metric
R23: 100k; R_0603_1608Metric
R30: 36k; R_0402_1005Metric
R34: 31k6; R_0603_1608Metric
R35: 10k2; R_0603_1608Metric
R39: 10k; R_0603_1608Metric
R41, R42: 27R4; R_0402_1005Metric
SW2, SW3, SW4: SW_Push; SW_RS-032G05A3-SMRT
TC2, TC3, TC4: TC2030-IDC; Tag-Connect_TC2030-IDC-NL_2x03_P1.27mm_Vertical
TP2: CHIP_PU; TestPoint_Pad_D1.0mm
TP3: VBAT_SENSE; TestPoint_Pad_D1.0mm
TP4, TP7: 3V3OUT; TestPoint_Pad_D1.0mm
TP5: MOSI; TestPoint_Pad_D1.0mm
TP6: MISO; TestPoint_Pad_D1.0mm
TP8: SCLK; TestPoint_Pad_D1.0mm
TP9: CS0; TestPoint_Pad_D1.0mm
TP10: CS1; TestPoint_Pad_D1.0mm
TP11: CS2; TestPoint_Pad_D1.0mm
TP12: RP_RUN; TestPoint_Pad_D1.0mm
U2: ESP-PSRAM32; SOIC-8_3.9x4.9mm_P1.27mm
U3: SN65HVD230; SOIC-8_3.9x4.9mm_P1.27mm
U4: ESP32-S3R2; QFN-56
U5, U7: W25Q128JVS; SOIC-8W_5.3x5.3mm_P1.27mm
U6: WS2815B; worldsemi-WS2815B-MFG
U8: ADP2303ARDZ-3.3; SOIC-8-1EP_3.9x4.9mm_P1.27mm_EP2.29x3mm
U9: COM-13909; XCVR_RFM69HW
U10: DRV8844PWP; HTSSOP-28-1EP_4.4x9.7mm_P0.65mm_EP2.85x5.4mm_ThermalVias
U11: RP2040; QFN-56
Y2, Y4: 40MHZ; Crystal_SMD_3225-4Pin_3.2x2.5mm
Y3: 32.7k; Crystal_SMD_MicroCrystal_CC7V-T1A-2Pin_3.2x1.5mm

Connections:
+1V1: C29.1, C31.1, C33.1, U11.23 (DVDD), U11.45 (VREG_VOUT), U11.50 (DVDD)
+3V3: C3.1, C4.1, C5.1, C7.1, C8.1, C9.1, C10.1, C11.1, C12.1, C13.1, C14.1, C15.1, C16.1, C28.1, C35.1, C38.1, C39.1, C40.1, C41.1, C45.2, C48.1, C49.1, C50.1, C51.1, C52.1, D2.2 (A), D3.2 (A), D4.2 (A), J3.4 (VDD), J4.B7, J5.1, L6.2, R4.2, R5.2, R15.1, R24.1, R34.1, R37.1, R38.1, R39.1, R40.1, R43.1, R44.1, R45.1, TP7.1, U2.8 (VCC), U3.3 (VCC), U4.2 (VDD3P3), U4.3 (VDD3P3), U4.20 (VDD3P3_RTC), U4.29 (VDD_SPI), U4.46 (VDD3P3_CPU), U4.55 (VDDA1), U4.56 (VDDA2), U5.8 (VCC), U7.8 (VCC), U9.13 (3.3V), U11.1 (IOVDD), U11.10 (IOVDD), U11.22 (IOVDD), U11.33 (IOVDD), U11.42 (IOVDD), U11.43 (ADC_AVDD), U11.44 (VREG_IN), U11.48 (USB_VDD), U11.49 (IOVDD)
/BST: C32.1, U8.1 (BST)
/CAN_N: J4.B12, R3.1, U3.6 (CANL)
/CAN_P: J4.B1, R3.2, U3.7 (CANH)
/CHIP_PU: J6.6, R4.1, SW2.1, TC2.6 (SWO), TP2.1, U4.4 (CHIP_PU)
/CONN_B2: J4.B2, U11.5 (GPIO3)
/CONN_B3: J4.B3, U11.8 (GPIO6)
/CONN_B10: J4.B10, U11.7 (GPIO5)
/CONN_B11: J4.B11, U11.6 (GPIO4)
/CONN_RP_USB_D_N: J4.B9, J5.4, R42.1
/CONN_RP_USB_D_P: J4.B4, J5.3, R41.1
/CP1: C46.1, U10.1 (CP1)
/CP2: C46.2, U10.2 (CP2)
/CTS: J6.5, R25.1, TC2.2 (SWDIO), U4.5 (GPIO0)
/DRV_RESET: R39.2, U10.16 (NRESET)
/DRV_SLEEP: U4.17 (GPIO12), U10.17 (NSLEEP)
/EN1: U4.9 (GPIO4), U10.26 (EN1)
/EN2: U4.11 (GPIO6), U10.24 (EN2)
/EN3: U4.13 (GPIO8), U10.22 (EN3)
/EN4: U4.16 (GPIO11), U10.20 (EN4)
/FB: R34.2, R35.1, U8.5 (FB)
/FSPICLK: J3.5 (CLK), J5.8, TP8.1, U4.41 (GPIO36), U9.4 (SCK), U11.3 (GPIO1)
/FSPICS0: J3.2 (CD/DAT3), TP9.1, U4.39 (GPIO34)
/FSPICS1: TP10.1, U4.14 (GPIO9), U9.5 (NSS)
/FSPICS2: TP11.1, U4.18 (GPIO13), U11.30 (GPIO19)
/FSPID: J3.7 (DAT0), J5.9, R40.2, TP5.1, U4.40 (GPIO35), U9.3 (MOSI), U11.4 (GPIO2)
/FSPIQ: J3.3 (CMD), J5.7, R43.2, TP6.1, U4.42 (GPIO37), U9.2 (MISO), U11.2 (GPIO0)
/GPIO0_BOOTSTRAP: R25.2, SW3.1
/GPIO1: U4.6 (GPIO1), U9.14 (DIO0)
/GPIO2: U4.7 (GPIO2), U9.6 (RESET)
/GPIO3: U4.8 (GPIO3), U10.27 (IN1)
/GPIO5: U4.10 (GPIO5), U10.25 (IN2)
/GPIO7: U4.12 (GPIO7), U10.23 (IN3)
/GPIO10: U4.15 (GPIO10), U10.21 (IN4)
/GPIO14: R38.2, TP12.1, U4.19 (GPIO14), U11.26 (RUN)
/GPIO21: R14.1, U3.8 (Rs), U4.27 (GPIO21)
/GPIO38: R30.2, R31.1, TP3.1, U4.43 (GPIO38)
/GPIO45: R26.1, U4.51 (GPIO45)
/GPIO46: R27.1, U4.52 (GPIO46)
/GPIO_CAN_N: U3.4 (R), U4.23 (GPIO17)
/GPIO_CAN_P: U3.1 (D), U4.24 (GPIO18)
/GPIO_GPO1: Q2.2 (G), U11.40 (GPIO28_ADC2)
/GPIO_GPO2: Q2.4 (G), U11.39 (GPIO27_ADC1)
/GPIO_GPO3: Q3.2 (G), U11.38 (GPIO26_ADC0)
/GPIO_GPO4: Q3.4 (G), U11.37 (GPIO25)
/GPIO_GPO5: Q4.4 (G), U11.35 (GPIO23)
/GPIO_GPO6: Q4.2 (G), U11.36 (GPIO24)
/GPIO_USB_D_N: R16.1, U4.25 (GPIO19)
/GPIO_USB_D_P: R17.1, U4.26 (GPIO20)
/GPO1: J4.A1, Q2.7 (D), Q2.8 (D)
/GPO2: J4.A2, Q2.5 (D), Q2.6 (D)
/GPO3: J4.A3, Q3.7 (D), Q3.8 (D)
/GPO4: J4.A4, Q3.5 (D), Q3.6 (D)
/GPO5: J4.A6, Q4.5 (D), Q4.6 (D)
/GPO6: J4.A5, Q4.7 (D), Q4.8 (D)
/LEDA: U6.4 (DIN), U6.6 (BIN), U11.41 (GPIO29_ADC3)
/LED_GREEN: R20.2, U11.27 (GPIO16)
/LED_RED: R19.2, U11.28 (GPIO17)
/LNA_IN: C17.2, L3.1, U4.1 (LNA_IN)
/MOTOR1_OUT1: J4.A7, U10.5 (OUTPUT1)
/MOTOR1_OUT2: J4.A8, U10.7 (OUTPUT2)
/MOTOR2_OUT1: J4.A9, U10.8 (OUTPUT3)
/MOTOR2_OUT2: J4.A10, U10.10 (OUTPUT4)
/MTCK: J8.1, TC4.4 (TCK), U4.44 (MTCK)
/MTDI: J8.4, TC4.3 (TDI), U4.47 (MTDI)
/MTDO: J8.2, TC4.6 (TDO), U4.45 (MTDO)
/MTMS: J8.3, TC4.2 (TMS), U4.48 (MTMS)
/PGOOD: R23.2, U8.4 (PGOOD)
/RF69_RF_ANT: R32.1, R33.1, U9.9 (ANT)
/RF69_RF_ANT_PCB: AE3.1 (A), R33.2
/RF69_RF_EXT: J2.2, R32.2
/RF_ANT: C20.2, L3.2, L4.1, R22.2, R28.2
/RF_ANT_EXT: J7.2, R28.1
/RP_SCLK: U7.6 (CLK), U11.52 (QSPI_SCLK)
/RP_SD0: U7.5 (DI(IO0)), U11.53 (QSPI_SD0)
/RP_SD1: U7.2 (DO(IO1)), U11.55 (QSPI_SD1)
/RP_SD2: U7.3 (IO2), U11.54 (QSPI_SD2)
/RP_SD3: U7.7 (IO3), U11.51 (QSPI_SD3)
/RP_SS: R36.1, R37.2, U7.1 (~CS), U11.56 (QSPI_SS)
/RP_SWCLK: TC3.4 (SWCLK), U11.24 (SWCLK)
/RP_SWD: TC3.2 (SWDIO), U11.25 (SWD)
/RP_USB_D_M: R42.2, U11.46 (USB_DM)
/RP_USB_D_P: R41.2, U11.47 (USB_DP)
/RP_XIN: C26.1, U11.20 (XIN), Y4.3
/RP_XOUT: C24.1, U11.21 (XOUT), Y4.1
/RTC_XTAL_N: C23.1, R8.1, R21.2, Y3.2
/RTC_XTAL_P: C19.1, R21.1, U4.21 (XTAL_32K_P), Y3.1
/RXD: J6.2, R6.1, TC2.3 (NRESET)
/SD_D1: J3.8 (DAT1), R44.2
/SD_D2: J3.1 (DAT2), R45.2
/SPICLK: R11.1, U2.6 (SCLK), U5.6 (CLK)
/SPICLK_P: C2.1, R2.1, U4.37 (SPICLK_P)
/SPICS0: R15.2, U4.32 (SPICS0), U5.1 (~CS)
/SPICS1: R5.1, U2.1 (~CE), U4.28 (SPICS1)
/SPID: R13.1, U2.2 (SO/SIO), U5.5 (DI(IO0))
/SPIHD: R9.1, U2.7 (SIO3), U5.7 (IO3)
/SPIQ: R12.1, U2.5 (SI/SIO), U5.2 (DO(IO1))
/SPIWP: R10.1, U2.3 (SIO2), U5.3 (IO2)
/SW: C32.2, L6.1, U8.8 (SW)
/TXD: J6.3, TC2.4 (SWCLK), U4.50 (U0RXD)
/USB_BOOT: R36.2, SW4.2
/USB_D_N: J4.B8, J5.5, R16.2
/USB_D_P: J4.B5, J5.6, R17.2
/VBAT: D5.2 (A), J4.A11
/VIN: C25.2, C43.2, C44.1, C47.1, D5.1 (K), JP2.2 (C), R23.1, R30.1, U8.2 (Vin), U8.3 (EN), U10.4 (VM-1), U10.11 (VM)
/WS2815B_VCC: C6.1, JP2.3 (B), U6.1 (VCC)
/WS2815B_VDD: JP2.1 (A), U6.2 (VDD)
/XTAL_N: C22.1, R7.1, Y2.3
/XTAL_P: C18.1, U4.54 (XTAL_P), Y2.1
GND: AE2.2 (Shield), C2.2, C3.2, C4.2, C5.2, C6.2, C7.2, C8.2, C9.2, C10.2, C11.2, C12.2, C13.2, C14.2, C15.2, C16.2, C17.1, C18.2, C19.2, C20.1, C21.1, C22.2, C23.2, C24.2, C25.1, C26.2, C28.2, C29.2, C31.2, C33.2, C35.2, C37.2, C38.2, C39.2, C40.2, C41.2, C42.2, C44.2, C45.1, C47.2, C48.2, C49.2, C50.2, C51.2, C52.2, H1.1, J2.1, J2.3, J3.6 (VSS), J3.P1 (SHIELD), J3.SWB, J4.A12, J4.B6, J5.2, J6.1, J7.1, J7.3, J8.5, Q2.1 (S), Q2.3 (S), Q3.1 (S), Q3.3 (S), Q4.1 (S), Q4.3 (S), R2.2, R14.2, R18.2, R26.2, R27.2, R31.2, R35.2, SW3.2, SW4.1, TC2.5 (GND), TC3.5 (GND), TC4.5 (GND), TP4.1, U2.4 (VSS), U3.2 (GND), U4.57 (GND), U5.4 (GND), U6.5 (GND), U7.4 (GND), U8.7 (GND), U8.9 (PADGND), U9.1 (GND), U9.8 (GND), U9.10 (GND), U10.6 (SRC12), U10.9 (SRC34), U10.14 (VNEG-2), U10.19 (LGND), U10.28 (VNEG), U10.29 (VNEG), U11.19 (TESTEN), U11.57 (GND), Y2.2, Y2.4, Y4.2, Y4.4
unnamed: AE2.1 (A), R22.1
unnamed: C21.2, L4.2
unnamed: C37.1, SW2.2
unnamed: C42.1, U10.15 (V3P3OUT)
unnamed: C43.1, U10.3 (VCP)
unnamed: D2.1 (K), R18.1
unnamed: D3.1 (K), R19.1
unnamed: D4.1 (K), R20.1
unnamed: J3.SWA, R24.2
unnamed: R6.2, U4.49 (U0TXD)
unnamed: R7.2, U4.53 (XTAL_N)
unnamed: R8.2, U4.22 (XTAL_32K_N)
unnamed: R9.2, U4.30 (SPIHD)
unnamed: R10.2, U4.31 (SPIWP)
unnamed: R11.2, U4.33 (SPICLK)
unnamed: R12.2, U4.34 (SPIQ)
unnamed: R13.2, U4.35 (SPID)

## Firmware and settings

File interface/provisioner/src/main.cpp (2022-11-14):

// Dear ImGui: standalone example application for SDL2 + OpenGL
// (SDL is a cross-platform general purpose library for handling windows, inputs, OpenGL/Vulkan/Metal graphics context creation, etc.)
// If you are new to Dear ImGui, read documentation from the docs/ folder + read the top of imgui.cpp.
// Read online: https://github.com/ocornut/imgui/tree/master/docs

#include "imgui.h"
#include "imgui_impl_sdl.h"
#include "imgui_impl_opengl3.h"
#include <stdio.h>

#ifdef __EMSCRIPTEN__
#include <emscripten.h>
#endif

#include <SDL.h>
#if defined(IMGUI_IMPL_OPENGL_ES2)
#include <SDL_opengles2.h>
#else
#include <SDL_opengl.h>
#endif

#include "provision.h"
#include "gitparams.h"

SDL_Window*     g_Window = NULL;
SDL_GLContext   g_GLContext = NULL;

static void main_loop(void* arg);

// Main code
int main(int argc, char** argv)
{
    // Setup SDL
    // (Some versions of SDL before <2.0.10 appears to have performance/stalling issues on a minority of Windows systems,
    // depending on whether SDL_INIT_GAMECONTROLLER is enabled or disabled.. updating to the latest version of SDL is recommended!)
    if (SDL_Init(SDL_INIT_VIDEO | SDL_INIT_TIMER) != 0)
    {
        printf("Error: %s\n", SDL_GetError());
        return -1;
    }

    // Decide GL+GLSL versions
#if defined(IMGUI_IMPL_OPENGL_ES2)
    // GL ES 2.0 + GLSL 100
    const char* glsl_version = "#version 100";
    SDL_GL_SetAttribute(SDL_GL_CONTEXT_FLAGS, 0);
    SDL_GL_SetAttribute(SDL_GL_CONTEXT_PROFILE_MASK, SDL_GL_CONTEXT_PROFILE_ES);
    SDL_GL_SetAttribute(SDL_GL_CONTEXT_MAJOR_VERSION, 2);
    SDL_GL_SetAttribute(SDL_GL_CONTEXT_MINOR_VERSION, 0);
#elif defined(__APPLE__)
    // GL 3.2 Core + GLSL 150
    const char* glsl_version = "#version 150";
    SDL_GL_SetAttribute(SDL_GL_CONTEXT_FLAGS, SDL_GL_CONTEXT_FORWARD_COMPATIBLE_FLAG); // Always required on Mac
    SDL_GL_SetAttribute(SDL_GL_CONTEXT_PROFILE_MASK, SDL_GL_CONTEXT_PROFILE_CORE);
    SDL_GL_SetAttribute(SDL_GL_CONTEXT_MAJOR_VERSION, 3);
    SDL_GL_SetAttribute(SDL_GL_CONTEXT_MINOR_VERSION, 2);
#elif defined(__EMSCRIPTEN__)
    // For the browser using Emscripten, we are going to use WebGL1 with GL ES2. See the Makefile. for requirement details.
    // It is very likely the generated file won't work in many browsers. Firefox is the only sure bet, but I have successfully
    // run this code on Chrome for Android for example.
    const char* glsl_version = "#version 100";
    //const char* glsl_version = "#version 300 es";
    SDL_GL_SetAttribute(SDL_GL_CONTEXT_FLAGS, 0);
    SDL_GL_SetAttribute(SDL_GL_CONTEXT_PROFILE_MASK, SDL_GL_CONTEXT_PROFILE_ES);
    SDL_GL_SetAttribute(SDL_GL_CONTEXT_MAJOR_VERSION, 2);
    SDL_GL_SetAttribute(SDL_GL_CONTEXT_MINOR_VERSION, 0);

    // Create window with graphics context
    SDL_GL_SetAttribute(SDL_GL_DOUBLEBUFFER, 1);
    SDL_GL_SetAttribute(SDL_GL_DEPTH_SIZE, 24);
    SDL_GL_SetAttribute(SDL_GL_STENCIL_SIZE, 8);
    SDL_DisplayMode current;
    SDL_GetCurrentDisplayMode(0, &current);
#else
    // GL 3.0 + GLSL 130
    const char* glsl_version = "#version 130";
    SDL_GL_SetAttribute(SDL_GL_CONTEXT_FLAGS, 0);
    SDL_GL_SetAttribute(SDL_GL_CONTEXT_PROFILE_MASK, SDL_GL_CONTEXT_PROFILE_CORE);
    SDL_GL_SetAttribute(SDL_GL_CONTEXT_MAJOR_VERSION, 3);
    SDL_GL_SetAttribute(SDL_GL_CONTEXT_MINOR_VERSION, 0);
#endif

    // Create window with graphics context
    SDL_GL_SetAttribute(SDL_GL_DOUBLEBUFFER, 1);
    SDL_GL_SetAttribute(SDL_GL_DEPTH_SIZE, 24);
    SDL_GL_SetAttribute(SDL_GL_STENCIL_SIZE, 8);
    SDL_WindowFlags window_flags = (SDL_WindowFlags)(SDL_WINDOW_OPENGL | SDL_WINDOW_RESIZABLE | SDL_WINDOW_ALLOW_HIGHDPI);
    static char buffer[255] = { 0 };
    snprintf(buffer, 255, "ConeRGB Configurator %s", git_describe());
    g_Window = SDL_CreateWindow(buffer, SDL_WINDOWPOS_CENTERED, SDL_WINDOWPOS_CENTERED, 1280, 720, window_flags);
    g_GLContext = SDL_GL_CreateContext(g_Window);
    if (!g_GLContext)
    {
        fprintf(stderr, "Failed to initialize GL context!\n");
        return 1;
    }

    SDL_GL_MakeCurrent(g_Window, g_GLContext);
    SDL_GL_SetSwapInterval(1); // Enable vsync

    // Setup Dear ImGui context
    IMGUI_CHECKVERSION();
    ImGui::CreateContext();
    ImGuiIO& io = ImGui::GetIO(); (void)io;
    io.ConfigFlags |= ImGuiConfigFlags_NavEnableKeyboard;       // Enable Keyboard Controls
    //io.ConfigFlags |= ImGuiConfigFlags_NavEnableGamepad;      // Enable Gamepad Controls
    io.ConfigFlags |= ImGuiConfigFlags_DockingEnable;           // Enable Docking
#ifndef __linux__ // TODO: enable on Windows
    io.ConfigFlags |= ImGuiConfigFlags_ViewportsEnable;         // Enable Multi-Viewport / Platform Windows
#endif
    //io.ConfigViewportsNoAutoMerge = true;
    //io.ConfigViewportsNoTaskBarIcon = true;

    // Setup Dear ImGui style
    ImGui::StyleColorsDark();
    //ImGui::StyleColorsLight();

    // When viewports are enabled we tweak WindowRounding/WindowBg so platform windows can look identical to regular ones.
    ImGuiStyle& style = ImGui::GetStyle();
    if (io.ConfigFlags & ImGuiConfigFlags_ViewportsEnable)
    {
        style.WindowRounding = 0.0f;
        style.Colors[ImGuiCol_WindowBg].w = 1.0f;
    }

    // Setup Platform/Renderer backends
    ImGui_ImplSDL2_InitForOpenGL(g_Window, g_GLContext);
    ImGui_ImplOpenGL3_Init(glsl_version);

    // Load Fonts
    // - If no fonts are loaded, dear imgui will use the default font. You can also load multiple fonts and use ImGui::PushFont()/PopFont() to select them.
    // - AddFontFromFileTTF() will return the ImFont* so you can store it if you need to select the font among multiple.
    // - If the file cannot be loaded, the function will return NULL. Please handle those errors in your application (e.g. use an assertion, or display an error and quit).
    // - The fonts will be rasterized at a given size (w/ oversampling) and stored into a texture when calling ImFontAtlas::Build()/GetTexDataAsXXXX(), which ImGui_ImplXXXX_NewFrame below will call.
    // - Use '#define IMGUI_ENABLE_FREETYPE' in your imconfig file to use Freetype for higher quality font rendering.
    // - Read 'docs/FONTS.md' for more instructions and details.
    // - Remember that in C/C++ if you want to include a backslash \ in a string literal you need to write a double backslash \\ !
    //io.Fonts->AddFontDefault();
    //io.Fonts->AddFontFromFileTTF("c:\\Windows\\Fonts\\segoeui.ttf", 18.0f);
    //io.Fonts->AddFontFromFileTTF("../../misc/fonts/DroidSans.ttf", 16.0f);
    //io.Fonts->AddFontFromFileTTF("../../misc/fonts/Roboto-Medium.ttf", 16.0f);
    //io.Fonts->AddFontFromFileTTF("../../misc/fonts/Cousine-Regular.ttf", 15.0f);
    //ImFont* font = io.Fonts->AddFontFromFileTTF("c:\\Windows\\Fonts\\ArialUni.ttf", 18.0f, NULL, io.Fonts->GetGlyphRangesJapanese());
    //IM_ASSERT(font != NULL);

    Provision::Init(argc, argv);
#ifdef __EMSCRIPTEN__
    // This function call won't return, and will engage in an infinite loop, processing events from the browser, and dispatching them.
    emscripten_set_main_loop_arg(main_loop, NULL, 0, true);
    fprintf(stderr, "emscripten_set_main_loop_arg return\n");
#else
    main_loop(NULL);
    // Cleanup
    Provision::Shutdown();
    ImGui_ImplOpenGL3_Shutdown();
    ImGui_ImplSDL2_Shutdown();
    ImGui::DestroyContext();

    SDL_GL_DeleteContext(g_GLContext);
    SDL_DestroyWindow(g_Window);
    SDL_Quit();
    return 0;
#endif
}

static void main_loop(void* arg)
{
    ImGuiIO& io = ImGui::GetIO();
    ImVec4 clear_color = ImVec4(0.45f, 0.55f, 0.60f, 1.00f);

    // Main loop
    bool done = false;
#ifndef __EMSCRIPTEN__
    while (!done)
#endif
    {
        // Poll and handle events (inputs, window resize, etc.)
        // You can read the io.WantCaptureMouse, io.WantCaptureKeyboard flags to tell if dear imgui wants to use your inputs.
        // - When io.WantCaptureMouse is true, do not dispatch mouse input data to your main application, or clear/overwrite your copy of the mouse data.
        // - When io.WantCaptureKeyboard is true, do not dispatch keyboard input data to your main application, or clear/overwrite your copy of the keyboard data.
        // Generally you may always pass all inputs to dear imgui, and hide them from your application based on those two flags.
        SDL_Event event;
        while (SDL_PollEvent(&event))
        {
            ImGui_ImplSDL2_ProcessEvent(&event);
            if (event.type == SDL_QUIT)
                done = true;
            if (event.type == SDL_WINDOWEVENT && event.window.event == SDL_WINDOWEVENT_CLOSE && event.window.windowID == SDL_GetWindowID(g_Window))
                done = true;
        }

        // Start the Dear ImGui frame
        ImGui_ImplOpenGL3_NewFrame();
#ifdef __EMSCRIPTEN__ 
        if (io.DeltaTime == 0.f || io.DeltaTime == 0.1f)
            io.DeltaTime = 1.f / 60.f;
#endif        
        ImGui_ImplSDL2_NewFrame();
        ImGui::NewFrame();

        // if docking is enabled, show the dockspace
        if(io.ConfigFlags & ImGuiConfigFlags_DockingEnable) {
            ImGui::DockSpaceOverViewport(ImGui::GetMainViewport());
        }

        // Rendering
        Provision::Render(&done);
        ImGui::Render();
        SDL_GL_MakeCurrent(g_Window, g_GLContext);
        glViewport(0, 0, (int)io.DisplaySize.x, (int)io.DisplaySize.y);
        glClearColor(clear_color.x * clear_color.w, clear_color.y * clear_color.w, clear_color.z * clear_color.w, clear_color.w);
        glClear(GL_COLOR_BUFFER_BIT);
        ImGui_ImplOpenGL3_RenderDrawData(ImGui::GetDrawData());

        // Update and Render additional Platform Windows
        // (Platform functions may change the current OpenGL context, so we save/restore it to make it easier to paste this code elsewhere.
        //  For this specific demo app we could also call SDL_GL_MakeCurrent(window, gl_context) directly)
        if (io.ConfigFlags & ImGuiConfigFlags_ViewportsEnable)
        {
            SDL_Window* backup_current_window = SDL_GL_GetCurrentWindow();
            SDL_GLContext backup_current_context = SDL_GL_GetCurrentContext();
            ImGui::UpdatePlatformWindows();
            ImGui::RenderPlatformWindowsDefault();
            SDL_GL_MakeCurrent(backup_current_window, backup_current_context);
        }

        SDL_GL_SwapWindow(g_Window);
    }
}

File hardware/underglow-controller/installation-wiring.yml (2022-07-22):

templates:
  Strip_X: &RGB_Strip
    type: strip
    pinlabels: [+12V, DI, DO, GND]
    image:
      src: images/wiring/WS2812B_LED.png

connectors:
  X1:
    type: Delphi_Sicma_24
    subtype: female
    pins:
      [
        A1, A2, A3, A4, A5, A6, A7, A8,
        B1, B2, B3, B4, B5, B6, B7, B8,
        C1, C2, C3, C4, C5, C6, C7, C8,
      ]
    pinlabels:
      [
        CH1_GND,  CH1_R, CH1_G, CH1_B, CH2_R, CH2_G,  CH2_B,  CH2_GND, 
        CH2_+12V, IGN,   CAN_H, CAN_L, GND,   USB_D-, USB_D+, +5V, 
        CH1_+12V, DI_1,  DI_2,  DI_3,  DI_4,  CH1_DO, CH2_DO, +12V,
      ]
    image:
      # src: images/wiring/Connector-Pinout.png
      src: images/wiring/Controller.png
      height: 500

  F1: &SolderJoin
    style: simple

  F2:
    <<: *SolderJoin

  F3:
    <<: *SolderJoin
    autogenerate: true
    color: BK

  X4:
    subtype: male
    pinlabels: [+12V, IGN, DI_1, GND]
    image:
      src: images/wiring/Plug-Male.png

  X5:
    subtype: male
    pinlabels: [+12V, IGN, DI_1, GND]
    image:
      src: images/wiring/Plug-Female.png

  X6:
    type: Bosch_Style
    subtype: socket
    pins: [30, 85, 86, 87A, 87]
    image:
      src: images/wiring/Relay-Socket.png

  Strip1_X1: &StripConnectorFemale
    type: JST SM
    subtype: female
    pinlabels: [+12V, DI, DO, GND]
    image:
      src: images/wiring/JST-SM-Female.png
  Strip1_X2: &StripConnectorMale
    type: JST SM
    subtype: female
    pinlabels: [+12V, DI, DO, GND]
    image:
      src: images/wiring/JST-SM-Male.png
  Strip1_X3:
    <<: *RGB_Strip
    notes: Front Bumper, 40 LEDs
  Strip1_X4:
    <<: *StripConnectorFemale
  Strip1_X5: 
    <<: *StripConnectorMale
  Strip1_X6:
    <<: *RGB_Strip
    notes: Side, 80 LEDs
  Strip1_X7:
    <<: *StripConnectorFemale
  Strip1_X8:
    <<: *StripConnectorMale
  Strip1_X9:
    <<: *RGB_Strip
    notes: Rear Bumper, 30 LEDs

  Strip2_X1: 
    <<: *StripConnectorFemale
  Strip2_X2:
    <<: *StripConnectorMale
  Strip2_X3:
    <<: *RGB_Strip
    notes: Front Bumper, 40 LEDs
  Strip2_X4:
    <<: *StripConnectorFemale
  Strip2_X5:
    <<: *StripConnectorMale
  Strip2_X6:
    <<: *RGB_Strip
    notes: Side, 80 LEDs
  Strip2_X7:
    <<: *StripConnectorFemale
  Strip2_X8:
    <<: *StripConnectorMale
  Strip2_X9:
    <<: *RGB_Strip
    notes: Rear Bumper, 30 LEDs

cables:
  W1: &PWR_Cable # from controller
    color_code: DIN
    colors: [RD, YE, GN, BU]
    wirelabels: [+12V, IGN, DI_1, GND]
    show_wirecount: false
  W2:
    <<: *PWR_Cable

  W5:
    color_code: DIN
    colors: [BU, BK]
    wirelabels: [RELAY_OUT, RELAY_GND]
    show_wirecount: false

  W6:
    color_code: DIN
    colors: [BK, WH, RD]
    wirelabels: [RELAY_GND, RELAY_SW, RELAY_+12V]
    show_wirecount: false
    notes: user must connect

  W7: &RGB_Wire
    show_name: false
    show_wirecount: false
    color_code: DIN
    colors: [RD, GN, BU, BK]

  Strip1_W1: &Strip_Cable
    color_code: DIN
    colors: [RD, GN, BU, BK]
    wirelabels: [+12V, DI, DO, GND]
    show_wirecount: false
  Strip1_W2: &RGB_Extension
    show_name: false
    show_wirecount: false
    color_code: DIN
    colors: [RD, GN, BU, BK]
    image:
      src: images/wiring/RGB-Extension.png
  Strip1_W3:
    <<: *RGB_Wire
  Strip1_W4:
    <<: *RGB_Wire
  Strip1_W5:
    <<: *RGB_Extension
  Strip1_W6:
    <<: *RGB_Wire
  Strip1_W7:
    <<: *RGB_Wire
  Strip1_W8:
    <<: *RGB_Extension
  Strip1_W9:
    <<: *RGB_Wire

  Strip2_W1: 
    <<: *Strip_Cable
  Strip2_W2: 
    <<: *RGB_Extension
  Strip2_W3:
    <<: *RGB_Wire
  Strip2_W4:
    <<: *RGB_Wire
  Strip2_W5:
    <<: *RGB_Extension
  Strip2_W6:
    <<: *RGB_Wire
  Strip2_W7:
    <<: *RGB_Wire
  Strip2_W8:
    <<: *RGB_Extension
  Strip2_W9:
    <<: *RGB_Wire
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

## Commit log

2022-06-28 Hardware v2 Rev A Release
    [0460-208-2031.stp, 0532610471--3DModel-STEP-361473.STEP, 0533980671--3DModel-STEP-361473.STEP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]
2022-06-28 start imx board
    [1040310811.stp, 1050170001.stp, 1468-0.step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]
2022-06-28 redesign into a "carrier" type setup
    [0460-208-2031.stp, 0532610471--3DModel-STEP-361473.STEP, 0533980671--3DModel-STEP-361473.STEP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]
2022-06-28 Start reworking imx board into the new form factor
    [0460-208-2031.stp, 0532610471--3DModel-STEP-361473.STEP, 0533980671--3DModel-STEP-361473.STEP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]
2022-06-28 haltech <-> na6 adapter
    [BOM-haltech-adapter.csv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]
2022-06-28 CM4 Prototype
    [629105150521.stp, CONEPROJ.kicad_pcb, TL3305BF260QG--3DModel-STEP-520916.STEP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]
2022-06-28 ESP Multi Gauge prototype
    [0508.stp, 5024940870.stp, CONEPROJ.kicad_pcb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]
2022-06-28 Add RP2040 Firmware prototype
2022-06-28 esp firmware scafolding
    [partitions.csv]
2022-06-28 Add pullups to sdcard
    [CONEPROJ.kicad_pcb, CONEPROJ.kicad_sch]
2022-06-28 Fix antenna impedance
    [CONEPROJ.kicad_pcb, CONEPROJ.kicad_sch]
2022-06-28 add debug headers, change pmic to something in stock
    [BOM-CONEPROJ.csv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]
2022-06-28 Multi gauge pcb design
    [0460-208-2031.stp, 0508.stp, 0532610471--3DModel-STEP-361473.STEP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]
2022-06-28 Update PCBs to share the same components
    * 3x flash memory
    * CAN transciever
    [CONEPROJ.kicad_pcb, CONEPROJ.kicad_sch, platform-esp.kicad_pcb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]
2022-06-28 Update images and project names
    [CONEPROJ.csv, RGB-controller.kicad_pcb, RGB-controller.kicad_sch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]
2022-06-28 Radio hardware and software design
    [BOM-RGB-controller.csv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]
2022-06-28 hardware updates: fix SPI bus on pico and flatten radio module
    [BOM-CONEPROJ.csv, BOM-RGB-controller.csv, BOM-epas-controller.csv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]
2022-06-28 Prototype motor controller device
    [BOM-epas-controller.csv, Motor-Control.kicad_sch, RGB-controller.kicad_pcb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]
2022-06-28 Prototype analog/digital input expander
    [input-expander.kicad_pcb, input-expander.kicad_sch]
2022-06-28 Hardware updates
    * fix messed up +12v pin
    * add a ground output for neopixels on both channels
    * add a i2c microphone
    * clean up schematic
    * calculate component values for the LED drivers
    [CAN-Bus.kicad_sch, Connectors.kicad_sch, ESP32-S3.kicad_sch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]
2022-06-28 Bom fillout + wiring
    [Connectors.kicad_sch, ESP32-S3.kicad_sch, External-IO.kicad_sch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]
2022-06-28 hw updates based on prototype issues
    * Removes unused hardware and firmware projectes
    * Adds some documentation and bom
    * cleanup READMEs
    [BOM-epas-controller.csv, BOM-haltech-adapter.csv, CAN-Bus.kicad_sch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]
2022-07-01 Add sqlite database for configuring the device
2022-07-01 hardware updates from board bringup
    [External-IO.kicad_sch, Power.kicad_sch, RGB-controller.kicad_pcb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]
2022-07-01 Layout updates
    [External-IO.kicad_sch, RGB-controller.kicad_pcb, RGB-controller.kicad_sch]
2022-07-01 V5 Rev B Hardware release
    [BOM-RGB-controller.csv, ESP32-S3.kicad_sch, External-IO.kicad_sch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]
2022-07-04 implement register-based VM and assembler
2022-07-06 oops cooked a board
2022-07-08 Add FET drivers
    [External-IO.kicad_sch, RGB-controller.kicad_pcb, RGB-controller.kicad_sch]
2022-07-09 Start multi-gauge again
    [CAN-Bus.kicad_sch, Connectors.kicad_sch, ESP32-S3.kicad_sch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]
2022-07-10 start integrating firmware
    [partitions.csv]
2022-07-13 hw updates based on latest boards
    [ESP32-S3.kicad_sch, External-IO.kicad_sch, RGB-controller.kicad_pcb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]
2022-07-13 Board bringup complete, move to real firmware
2022-07-20 this is the firmware that is on Easyy's and Jake's device
2022-07-26 Implement PWM RGB control
2022-07-31 Hardware updates, firmware updates blah blah blah
    [ESP32-S3.kicad_sch, RGB-controller.kicad_pcb, RGB-controller.kicad_sch]
2022-08-09 hardware updates
    [Connectors.kicad_sch, ESP32-S3.kicad_sch, External-IO.kicad_sch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]
2022-08-10 more hardware updates. need to sort out the antenna for the radio next
    [ESP32-S3.kicad_sch, External-IO.kicad_sch, RGB-controller.kicad_pcb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]
2022-08-11 hw updates pt 69 thousand
    [CAN-Bus.kicad_sch, Connectors.kicad_sch, ESP32-S3.kicad_sch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]
2022-08-26 Scafold V2 Framework
    This refactors a lot of documentation and shell/support code to
    implement a new core of the underglow controller device
2022-11-13 Provision: Add small native app for device provisioning and tuning
2022-11-14 firmware: companion: remove old implementations
    [partitions.csv]
2022-11-15 hardware: prepare for production run
    [BOM-RGB-controller.csv, CAN-Bus.kicad_sch, ESP32-S3.kicad_sch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]
2022-11-15 hardware: select some JLCPCB components
    [CAN-Bus.kicad_sch, Connectors.kicad_sch, ESP32-S3.kicad_sch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]
2022-11-17 hardware: assign more JLC parts
    [ESP32-S3.kicad_sch, External-IO.kicad_sch, Power.kicad_sch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]
2022-11-17 fix hole locations
    [RGB-controller.kicad_pcb]
2022-11-17 update hole footprints and final hole location
    [Connectors.kicad_sch, RGB-controller.kicad_pcb, RGB-controller.kicad_sch]
2022-11-29 add case models
2022-12-01 hardware: add teardrops to vias
    [Connectors.kicad_sch, ESP32-S3.kicad_sch, RGB-controller.kicad_pcb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]
2023-03-21 add mounting and antenna holes to case
